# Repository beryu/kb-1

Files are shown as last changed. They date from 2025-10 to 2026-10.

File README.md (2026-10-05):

# komoro

komoroは、19mmトラックボールを搭載した左右分割キーボードです。

コンパクトな17mmピッチのカラムスタッカード配列を採用し、左右合わせて48キーを搭載しています。
トラックボールの高さを低く抑えることで、キーを打つときや持ち運びの邪魔になりにくくしています。
コントローラーにはSeeed Studio XIAO nRF52840 Plusを採用しています。XIAOは右側だけに搭載し、左右間はSamtec FTSHヘッダとFFSD-06-D-10.00-01-Nケーブルで接続します。PCとはBluetoothで通信しますが、動作中は右側USB-Cから常に給電する必要があります。

| 左側PCB | 右側PCB |
| --- | --- |
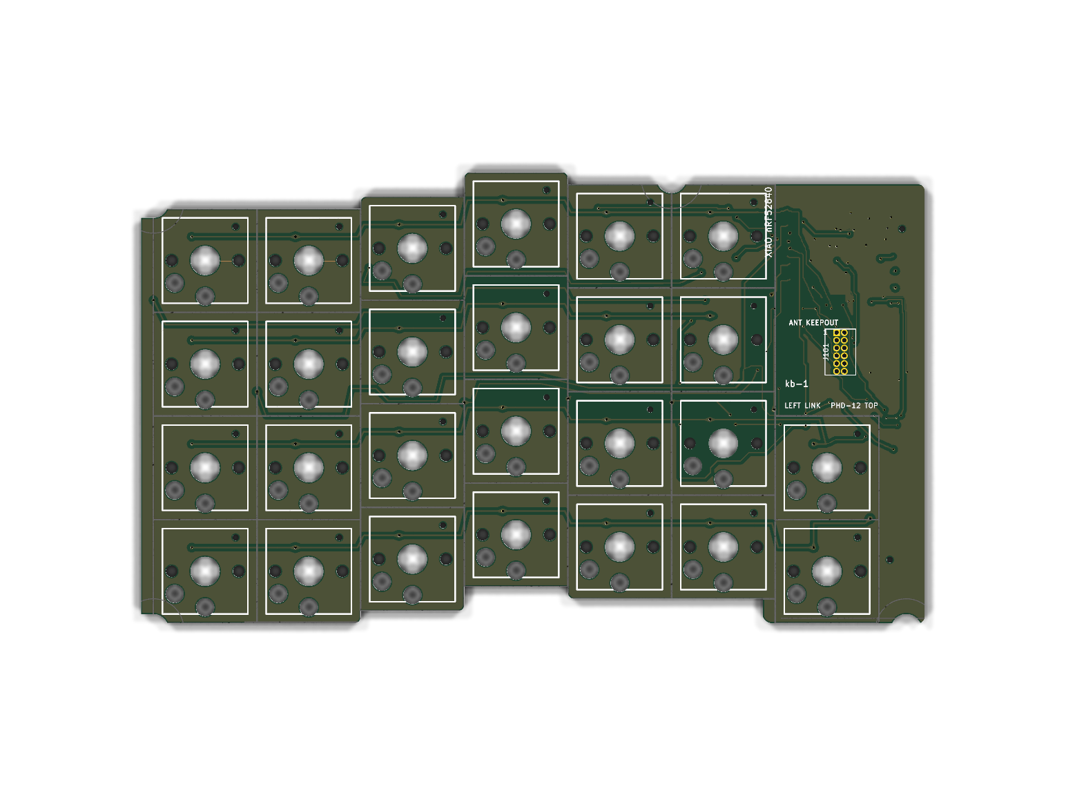
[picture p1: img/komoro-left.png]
komoro 左側PCB
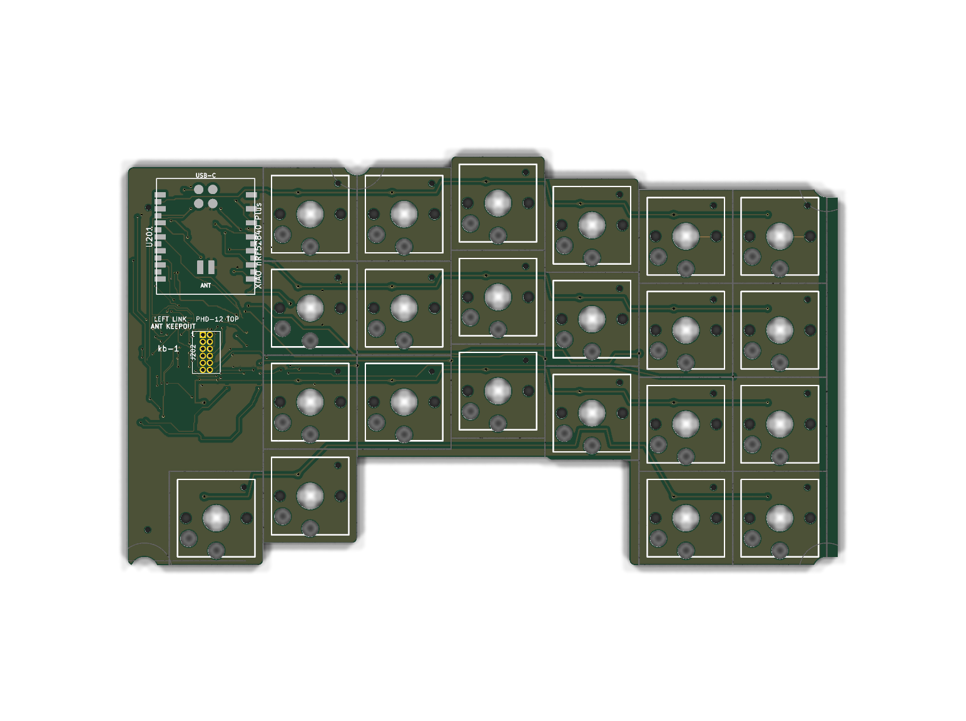
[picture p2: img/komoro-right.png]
komoro 右側PCB
|  |  |

※画像は旧リビジョンの基板です。現行のコネクタや部品配置は[`pcb/`の製造用PCBデータ](pcb/)を確認してください。

## [ビルドガイド](build-guide.md)

## 特徴

* 17mmピッチのカラムスタッカード配列
  * 左26キー、右22キーの48キー構成です。
* USB-C給電・Bluetooth接続
  * PCとの通信にはBluetoothを使用します。
  * 使用中は右側XIAOへモバイルバッテリーまたはUSB電源から常に給電する必要があります。
  * 電源スイッチはなく、USB-Cケーブルの接続／取り外しで電源を操作します。
  * 左右間は、Samtec FFSD-06-D-10.00-01-Nケーブルで接続します。
* Seeed Studio XIAO nRF52840 Plusを採用
  * XIAOは右側だけに搭載し、左側はコントローラーを持たない受動基板です。
* トラックボールの設置位置が調整可能
  * トラックボールを取り付ける位置を調整して、自分にとって一番操作しやすい位置に設置できます。ボールの高さを抑えたことでキーを打つときの邪魔になりにくくなっています。
* ZMK対応
  * [komoro専用ファームウェア](https://github.com/beryu/zmk-keyboard-kb-1)を公開しています。
  * keymap-editorやZMK Studioを使用して簡単にキーマップが変更できます。

## 使用上の注意

* 異臭や煙が出たときは、ただちにUSB-C電源を外して使用を中止してください。
* 左右を接続するFFSDケーブルは、USB-C電源を外した状態で抜き差ししてください。
* USB-C電源とケーブルは、破損や発熱のない適合品を使用してください。

## 設計データについて

本リポジトリでは、komoroの基板設計データと19mmトラックボールケースの設計データを公開しています。

19mmトラックボールケースには、PAW3222センサーモジュールのズレを抑える[ガイド追加版STL](3d-models/STL/trackball-case-19mm-ortho-sensor-fit-Body.stl)を用意しています。寸法と印刷・再生成方法は[センサー溝の調整説明](3d-models/FreeCAD/TRACKBALL-SENSOR-FIT.md)を確認してください。再生成の入力に使う従来版STLは残し、旧トラックボールケースのFreeCADファイルは削除しています。本体ケースのFreeCADデータとSTLは現行PCB外形、左右上面のFFSDコネクタ、右側USB-Cに合わせて更新しています。印刷前に実部品との干渉を確認してください。

ライセンスにしたがって自由に利用していただいて構いませんが、問い合わせには対応しません。

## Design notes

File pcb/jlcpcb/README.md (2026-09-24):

# JLCPCB発注データ

Samtec FTSH-106-01-L-D-Kを左右とも上面に縦挿しする基板から生成します。左J101と右J202はともに0°で、標準の両端FFSDケーブルに合わせて同番号端子へ同じ信号を割り当てています。左右ともKiCad DRCで未接続0件、短絡・クリアランス違反0件です。製造発注前に警告内容、ケーブルの実物結線、筐体内の高さ・取り回しを確認してください。

## 左右間ケーブル

既製の Samtec `FFSD-06-D-10.00-01-N`（2×6極、254 mm、標準両端ソケット）を使用します。`-RW`または`-R`型は使用しません。左J101→右J202は同番号対応です。

| 左J101 | 右J202 | 信号 |
| ---: | ---: | --- |
| 1 | 1 | LROW2 |
| 2 | 2 | COL4 |
| 3 | 3 | LROW0 |
| 4 | 4 | LROW1 |
| 5 | 5 | COL5 |
| 6 | 6 | COL6 |
| 7 | 7 | COL3 |
| 8 | 8 | COL2 |
| 9 | 9 | COL1 |
| 10 | 10 | GND |
| 11 | 11 | LROW3 |
| 12 | 12 | COL0 |

組み立て前に実物のケーブルで上記12組の導通と隣接ピン間の短絡がないことを確認してください。特にGND（10→10）の誤接続は通電前に確認します。

`bash pcb/jlcpcb/generate.sh` をリポジトリのルートで実行すると、`output/` に左右それぞれのGerber ZIP、BOM、CPL、DRCレポートに加え、左右を1回のPCBA注文にまとめるカスタマーパネルと`combined-drc.txt`を生成します。左右とパネルの電気的DRCエラーまたは未接続が1件でもある場合は生成を中断します。

結合パネルの生成にはKiKit 1.8.0が必要です。KiCad付属Pythonへ次のようにインストールしてください。

```sh
/Applications/KiCad/KiCad.app/Contents/Frameworks/Python.framework/Versions/Current/bin/python3 \
  -m pip install --user -r pcb/jlcpcb/requirements-panel.txt
```

JLCPCBでは次の結合ファイルを使用します。

- PCB: `output/combined-gerbers.zip`
- BOM: `output/combined-bom.csv`
- CPL: `output/combined-cpl.csv`

見積画面では`Different Design: 2`、`Delivery Format: Panel by Customer`、`PCB Color: White`、`Silkscreen: Black`、`PCBA Type: Standard`を選択します。実装対象のダイオード48個はすべて裏面配置なので、`Assembly Side: Bottom Side`を選択してください。BOM確認画面のファイル形式は`Complete File`を選択してください。ハンドリングレールとフィデューシャルは`Added by JLCPCB`のままとします。

このパネルは左右のPCBを2 mm間隔で縦に配置し、3か所のマウスバイトタブで連結する生成物です。レール追加前の外形範囲は約128.6 x 150.2 mmです。左右別々のファイルは、個別発注や診断用として引き続き生成します。

左右間の3か所のタブには直径0.5 mmのマウスバイト穴を両端に8個ずつ設け、穴の間の残り幅を約0.36 mmにしています。切断線を基板側に0.2 mm寄せているため、折った後の突起を抑えられます。ただしマウスバイトの細かな凹凸は残るため、外形を完全に平滑にするには分離後の軽い仕上げが必要です。JLCPCBの標準Vカットはパネル全幅を通る直線に限られ、この2 mmの隙間をまたぐ局所的な3本のタブだけには適用できません。

## ネジ用の逃げ

左右の基板に各4か所、合計8か所の円弧状の逃げを`Edge.Cuts`で設けています。元の`MountingHole_5mm`フットプリントは中心が基板外にあり、基板外形を切り欠かないままパネル化で一部が落ちていました。修正後は実際の基板外形がネジ位置を避けます。生成時に8か所の外形とネジ中心の距離を検査します。

修正前にアップロードしたGerberのJLCPCBプレビューにはこの逃げが反映されません。発注には再生成した`output/combined-gerbers.zip`をアップロードし、プレビューで8か所の円弧状の切り欠きを確認してください。

## ビア寸法

左右基板と結合パネルの全ビアは、穴径0.3 mm以上・外径0.5 mm以上です。JLCPCB見積画面の`Min via hole size/diameter`は標準の`0.3mm/(0.4/0.45mm)`を選択できます。生成時に全ビアの寸法を検査します。旧Gerberには0.2 mmと0.25 mmの穴があるため、必ず新しい`combined-gerbers.zip`をアップロードしてください。

## PCBA対象

- JLCPCB実装: 1N4148Wダイオード
- 手はんだ: 右側XIAO nRF52840 Plus、左右のSamtec FTSH-106-01-L-D-K（上面からFFSDケーブルを挿入）、Chocソケット、FFC変換基板

BOM/CPLは基板フットプリントの`exclude_from_bom`、`exclude_from_pos_files`および`LCSC`フィールドから生成します。JLCPCBへのアップロード後は、ダイオードの向きと当日在庫をプレビュー画面で必ず確認してください。

結合GerberはJLCPCBの基板外形認識と整合するKiCad CLIで生成します。左右の正本PCBには、パネル化の前に通常のCLI DRCを実行します。

## 回路図の再生成

左右の回路図はPCBを正として生成しています。PCBのパッド／ネットを変更した後は、KiCad付属Pythonで`pcb/generate_schematic_from_pcb.py <board> <output schematic> <left|right>`を実行し、親回路図に対してERCとネットリスト照合を行ってください。

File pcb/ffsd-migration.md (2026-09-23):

# FFSD左右間接続の設計記録

既製ケーブルは Samtec `FFSD-06-D-10.00-01-N`（2×6極、254 mm、標準の両端付き）を採用する。基板側は手はんだ可能なスルーホール `FTSH-106-01-L-D-K` を左右に1個ずつ使用する。両方を上面の縦挿しとし、ストレートケーブルに合わせて左右の**同番号端子に同じ信号**を割り当てる。

| 端子 | 左の信号 | 右の信号 |
| ---: | --- | --- |
| 1 | LROW2 | LROW2 |
| 2 | COL4 | COL4 |
| 3 | LROW0 | LROW0 |
| 4 | LROW1 | LROW1 |
| 5 | COL5 | COL5 |
| 6 | COL6 | COL6 |
| 7 | COL3 | COL3 |
| 8 | COL2 | COL2 |
| 9 | COL1 | COL1 |
| 10 | GND | GND |
| 11 | LROW3 | LROW3 |
| 12 | COL0 | COL0 |

基板側は `Library.pretty/Samtec_FTSH-106-01-L-D-K.kicad_mod` を使用する。Samtec の [FTSH製品図面](https://suddendocs.samtec.com/prints/ftsh-1xx-xx-xxx-d-xx-mkt.pdf) に従い、端子ピッチ1.27 mm、-K樹脂外形5.08 × 7.54 mm とした。穴径0.71 mmは Samtec の [推奨PCBレイアウト](https://suddendocs.samtec.com/prints/fts-dth.pdf) に基づく。ランド外径1.11 mmで片側の環状銅幅0.20 mmを確保し、マスク開口はランドと同寸にして隣接開口間0.16 mmとした。[JLCPCBのPTH環状銅幅・マスクブリッジ仕様](https://jlcpcb.com/capabilities/Capab)に合わせた。表面実装ではなくスルーホールで手はんだを想定する。

左J101は (123.2, 70.0) mm、右J202は (52.0, 151.0) mm を中心に、ともにF.Cu側、回転0°で実装する。ヘッダを上から差し込み、右側ではXIAO下部に置く。ケーブルは Samtec の標準 `FFSD-06-D-10.00-01-N` とし、`-RW`（Reverse Wiring）や `-R`（Reversed）型は使わない。左右の同番号ピンへ同じ信号を割り当てている。通電前に製品サンプルで12極の同番号導通、隣接間短絡、筐体内のキーとケーブル取り回しを確認する。

[FTSH-106-01-L-D-K の製品仕様](https://www.digikey.com/en/products/detail/samtec-inc/FTSH-106-01-L-D-K/7433351)では、はんだ側ポスト長は2.29 mm。基板厚1.6 mmを差し引いた裏面側の公称突き出しは約0.69 mmで、約3 mmの裏面空間に対し余裕がある。実際にははんだフィレットの高さもあるため、組立試作で確認する。

2026-09-23 のKiCad DRCでは、左右単体および結合パネルとも未接続0、短絡・クリアランス違反0。既存設計由来のシルク被りや不要な短い銅箔等の警告は残る。`replace_phd_with_ffsd.py` は設計過程の試行用スクリプトであり、製造時は正本PCBと `jlcpcb/output/` を使用する。

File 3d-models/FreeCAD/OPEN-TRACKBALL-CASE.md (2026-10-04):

# 19.05 mm 開放型トラックボールケース（試作）

写真のようにボール周囲の樹脂を減らすための別ケースです。既存のセンサーガイド追加版を基準に、ベアリング支持部の間の壁を3か所取り除いています。元ファイルは変更していません。完全に異なる取り付け方式へ変更するものではなく、センサー収納部・後方支持部・固定穴を引き継いだ開放型です。

- 印刷用：[`trackball-case-19mm-open-Body.stl`](../STL/trackball-case-19mm-open-Body.stl)
- FreeCAD表示用：[`trackball-case-19mm-open.FCStd`](trackball-case-19mm-open.FCStd)
- 生成スクリプト：[`generate-open-trackball-case.py`](generate-open-trackball-case.py)
- 検証結果：[`trackball-case-19mm-open-Body.validation.json`](../STL/trackball-case-19mm-open-Body.validation.json)

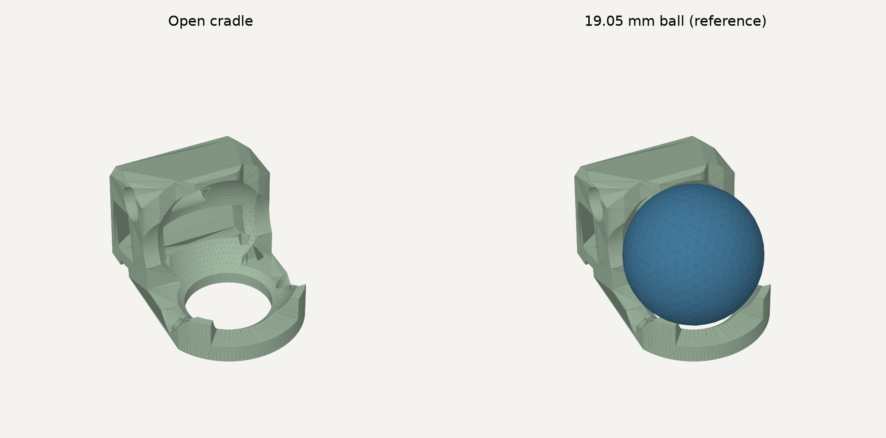
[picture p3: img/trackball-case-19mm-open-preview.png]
ケース単体とボール配置


## 構造

19.05 mm POMボール、4×1.5×2 mmベアリング3個、M1.4×5 mmのベアリング固定ねじ、既存センサーモジュールを使う想定です。後方のM2固定穴とセンサー溝を維持しています。下部2.5 mmのフレームを残し、前方と左右に開口を設けています。中央の底穴も元形状のままです。

ベアリング支持部の残る角度は前方の左右38〜78度と−78〜−38度です。後方のセンサー収納部はX≤−6 mmの領域を残しています。球面を樹脂で支える設計ではなく、組み立て時にはベアリング3個で支えてください。

保持用の壁が減るため、持ち運び時にボールが外れる可能性があります。スナップ保持は保証していません。強度・印刷公差・ベアリング外輪の回転余裕・実センサー部品との干渉は実物で未検証です。

## データ上の検証

元ケース内面の球面から求めた中心(0, 0, 9.8) mmを基準にしています。支持された実ボールの中心はまだ実測していません。この公称位置で半径10.025 mmの球（ボール半径9.525 mm＋0.50 mm）との重なり体積が0であることを、保存したSTLの再読み込み後に検証しました。

元の旧版とセンサーガイド追加版も、この同じ公称位置・半径では重なり体積0でした。したがって、現物の引っかかりをガイド追加だけのせいと断定する根拠はありません。開口は擦れ得る壁を減らし、接触の確認と清掃をしやすくする変更です。

閉じたメッシュ、面の向き、接続成分1、後方収納部と下部フレームの維持を検証しています。ベアリングやねじの実部品モデルを含む組立干渉検証ではありません。プレビューの球も位置参照用です。

## 印刷・確認

底面を下に配置してください。薄い壁とセンサー溝があるため、スライサーで壁の欠落やオーバーハングを確認し、必要なサポートを付けます。ベアリング座と溝に残ったサポートやバリは取り除いてください。

まずセンサーなしでベアリングとボールを組み、各方向に転がして擦れと支持部のたわみを確認してください。次にセンサーを装着して位置を調整します。取り付けねじの締め付け前後でも動きを確認してください。実機確認までは旧ケースの置き換え推奨にはしていません。

## 再生成

`numpy`、`trimesh`、`manifold3d`を使用します。プレビューには`matplotlib`が必要です。

```sh
python 3d-models/FreeCAD/generate-open-trackball-case.py \
  --preview img/trackball-case-19mm-open-preview.png \
  --freecadcmd /Applications/FreeCAD.app/Contents/Resources/bin/freecadcmd \
  --cad-output 3d-models/FreeCAD/trackball-case-19mm-open.FCStd
```

FreeCADを使わずSTLだけ生成する場合は、`--freecadcmd`と`--cad-output`を省略できます。FCStdは生成済みメッシュと非表示の参照球を収録しています。メッシュを寸法駆動するCADではなく、形状の変更はスクリプトの`BASE_HEIGHT`と`WINDOWS`で行ってください。

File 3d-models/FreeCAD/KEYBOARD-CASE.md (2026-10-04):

# Keyboard case generator

`generate-keyboard-case.py` reads both KiCad PCB files and regenerates the
bottom trays and top plates in FreeCAD. The PCB outline and the locations and
rotations of the key switches and XIAO footprints therefore stay synchronized
with the PCB design.

## Generate

From a terminal on macOS with FreeCAD installed in `/Applications`:

```sh
/Applications/FreeCAD.app/Contents/Resources/bin/freecadcmd \
  -c "exec(open('3d-models/FreeCAD/generate-keyboard-case.py').read())"
```

It can also be pasted directly into FreeCAD's Python console. Use the complete
absolute path on one line:

```python
exec(open('/absolute/path/to/torabo-tsuki-om/3d-models/FreeCAD/generate-keyboard-case.py').read())
```

The script detects checkouts stored under the conventional
`~/ghq/github.com/<account>/torabo-tsuki-om` path even though the FreeCAD Python
console does not define `__file__`. For a checkout elsewhere, start FreeCAD
from the repository directory or set `TORABO_TSUKI_OM_ROOT` before launching
FreeCAD.

Outputs are written to `3d-models/FreeCAD/generated/`:

- one editable FreeCAD document containing both halves;
- STL files for printing;
- STEP files for exchange and downstream CAD edits.

Open `torabo-tsuki-om-keyboard-case.FCStd` in FreeCAD. The model tree separates
the left/right halves, bottom trays, top plates, and hidden PCB references.

## Assembly hardware

The complete left/right enclosure uses the following printed parts and
hardware:

| Item | Quantity | Notes |
| --- | ---: | --- |
| [Left bottom tray](generated/left-bottom-tray.stl) | 1 | 3D printed |
| [Left top plate](generated/left-top-plate.stl) | 1 | 3D printed |
| [Right bottom tray](generated/right-bottom-tray.stl) | 1 | 3D printed |
| [Right top plate](generated/right-top-plate.stl) | 1 | 3D printed |
| M2 heat-set insert | 8 | Four per half. [Japan Drive-It Sonic Lock M2-3.0, MonotaRO order code 42131126](https://www.monotaro.com/p/4213/1126/) fits the 3.2 mm diameter, 4.0 mm deep pilot. It is sold in packs of six, so order two packs. |
| M2 x 3.5 mm low-profile screw | 8 | Original design specification for fastening the two top plates. |
| M2 x 4 mm ultra-low-head screw | 8 | Verified top-plate alternative: [AHN2 stainless screw, MonotaRO order code 69132245](https://www.monotaro.com/p/6913/2245/). Its M2 x 0.4 thread and 0.3 mm-high head fit; the extra 0.5 mm increases insert engagement to about 2.5 mm. One 13-piece pack is sufficient. |
| Thin self-adhesive rubber foot | 8 | Recommended for grip and bottom protection. |

Use either the 3.5 mm or 4 mm top-plate screws, not both. The printed bosses
replace the 4.5 mm spacers used by the original PCB top/bottom-plate stack, so
separate spacers, washers, and ordinary nuts are not required. The M2 x 4 mm
alternative above has only been checked for the enclosure top plates; continue
to use the specified M2 x 3.5 mm screw for the separate trackball-case mount.

## Design intent

The generator reads the current left and right `Edge.Cuts` and footprints. The
2026-09 PCB revision has a single right-side XIAO, no AAA holders or power
switches, and a vertical Samtec FTSH header on each side. The case has been
regenerated from those boards.

- The bottom is 1.5 mm thick, with 0.25 mm horizontal PCB clearance and a
  1.8 mm perimeter wall. The PCB is intended to sit with its top face level
  with the bottom-tray rim, supported by compressed foam around the inner
  perimeter. With this placement its underside is 3.0 mm above the tray floor;
  the FreeCAD PCB reference shows this installed position. A nominal 5 mm foam
  strip placed on the floor would compress to 3 mm, subject to the actual foam
  and screw preload.
- A 7 mm wide, 1 mm deep underside groove runs across each tray. A 9 mm wide,
  1 mm high rib directly above it leaves 1 mm of side material on each side
  and restores 1.5 mm of total material at the groove. The rib follows the
  calculated midpoint of adjacent Choc socket rows, including their stagger;
  both grooves align when the trays are mirrored bottom-to-bottom. The path
  avoids the magnet pockets. The plan-view corners have a 2.0 mm radius, and
  the groove mouth has a straight 0.4 mm chamfer, making its cross-section
  trapezoidal at the opening instead of leaving sharp cable-contact edges.
  Cable width, repeated
  folding at the far end,
  and the assembled cable route still need checking with the actual cable.
- Each bottom tray has four top-open pockets for 12 x 1 mm magnets. As in the
  supplied reference STL, the pockets are 12.1 mm in diameter and 1.0 mm deep,
  leaving 0.5 mm of material underneath. The upper pair follows the stepped
  case edge; each pocket has 7.0 mm clearance to its adjacent outer walls.
  The right positions are mirrored so all four pairs align when the two tray
  bottoms face each other for carrying.
- Each top plate is 1.5 mm thick, with its underside at the intended PCB top
  surface, and has
  20 switch windows measuring 14.2 x 14.0 mm, positioned from the KiCad
  footprints. The top plates and bottom trays are 3D-printed case parts.
- Each FTSH header has a 6.4 x 13.0 mm through-opening in its top plate for
  the FFSD-06 socket and upward cable exit. [Samtec's FFSD series drawing](https://suddendocs.samtec.com/catalog_english/ffsd.pdf) gives
  the unrelieved six-position socket body as 5.08 x 11.81 mm; the opening
  provides about 0.6 mm clearance per side. The left J101 and right J202
  footprints are both at 0 degrees, and each opening is centred on its
  connector body rather than the pin-1 footprint origin.
- Only the right plate has a raised XIAO cover and the right tray has a USB-C
  wall opening. The cover retains the white-label window, reset access hole,
  and LED viewing holes. The visible window is 10.5 x 12.5 mm, based on the
  supplied `xiao-nrf52840-plus-v2.step` label (10.2 x 12.2 mm). A wider
  11.2 x 13.2 mm underside pocket clears its metal shield (10.6 x 12.6 mm)
  while a 0.3 mm masking lip hides nearly all of the black border. Only the
  central USB-C region rises in a convex profile
  when viewed from the cable entry; the lower 9.8 mm pocket narrows toward the
  connector crown while the reset and LED areas retain the original roof.
  The metal shell extends 1.51 mm beyond the XIAO PCB and reaches 4.41 mm
  above the underside solder-pad plane. The pocket clears the complete STEP
  assembly with the bare XIAO held against the inverted top plate, and its
  roof remains 1.5 mm thick. The separate 12 mm wall opening provides the
  cable passage. The top plate also has a 12 mm wide, full-height notch starting
  at local X=11.5 mm, 0.8 mm before the STEP receptacle mouth, so the raised
  roof does not protrude in front of the port or block the plug housing.
- Four M2 insert bosses per half follow the former mounting-hole centres. The
  current boards have routed `Edge.Cuts` screw reliefs in place of the old
  `MountingHole_5mm` footprints. The bosses are 4.6 mm in diameter, with 3.2 mm
  insert pilots, 4.0 mm deep from the lowered tray top. The bosses extend to
  the tray bottom so their routed-edge portions have no underside gaps; each
  top plate has 2.4 mm screw holes.
- The right PCB's trackball cutout has a 34 mm back edge and continues one
  17 mm switch column to the right. The tray floor spans both areas, extends
  4.7 mm south of the former front edge, and has a 2 mm radius at both exposed
  southern corners. Its southern lip is 2.5 mm from the slot edge. The 44.2 x
  2.4 mm fastening slot and its shallow underside
  screw-head recess are shifted 5 mm south to align with the trackball case's
  forward fixing-hole row while leaving at least 2 mm at the north edge.
  The separate trackball-case STL is about 29.8 x 20.8 mm in plan view.
  At the lower-right corner of the third switch column from the right, a
  3.45 mm FFC slit passes through the wall at the PCB's stepped edge. The
  floor remains its full 1.5 mm thick beneath the slit.

The four generated STL files and the editable FreeCAD document are in
`generated/`. The STEP files are also exported for CAD exchange. The STL
meshes are checked for closure during generation. Check the printed cable
connector and trackball fit with physical parts before ordering a full set.

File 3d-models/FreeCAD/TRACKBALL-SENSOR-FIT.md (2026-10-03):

# 19 mmトラックボールケースのセンサーモジュール用ガイド

印刷には [`trackball-case-19mm-ortho-sensor-fit-Body.stl`](../STL/trackball-case-19mm-ortho-sensor-fit-Body.stl) を使用してください。再生成の入力に使う元STLは残しています。旧FreeCADファイルは削除し、調整版FCStdへ置き換えています。

対象は [sekigon-gonnoc/small-mouse-sensor-module](https://github.com/sekigon-gonnoc/small-mouse-sensor-module) のPAW3222モジュールです。READMEの「14×8 mm」は概略寸法で、[公式寸法図](https://github.com/sekigon-gonnoc/small-mouse-sensor-module/blob/main/img/size.png) の基板外形は **13.4×7.4 mm** です。

## 両側に貫通したセンサー溝

センサー溝は **-Y側と+Y側の両方に貫通** しています。位置決めストッパーは設けず、どちらからでも基板を挿入・取り外しでき、反対側から押し戻すこともできます。

| 項目 | 調整版 |
| --- | --- |
| 挿入・取り外し | 両側から可能 |
| ガイド間の短辺寸法 | 7.7 mm（基板7.4 mmに対して片側0.15 mm） |
| 長辺方向 | 貫通。位置決めストッパーなし |
| 基板背面の凹み | 約2.8 mmを確保し、両側に貫通 |
| 光学窓側の部品用凹み | 元の2.5 mmを維持 |

センサーを元ケースと同じ向きで保持し、側面の溝に基板端を合わせて中央まで滑り込ませます。短辺方向のガイドで横ズレと回転を抑えますが、長辺方向はスライドできます。光学窓、ボール支持部、固定穴、ケースの最大外形は維持しています。

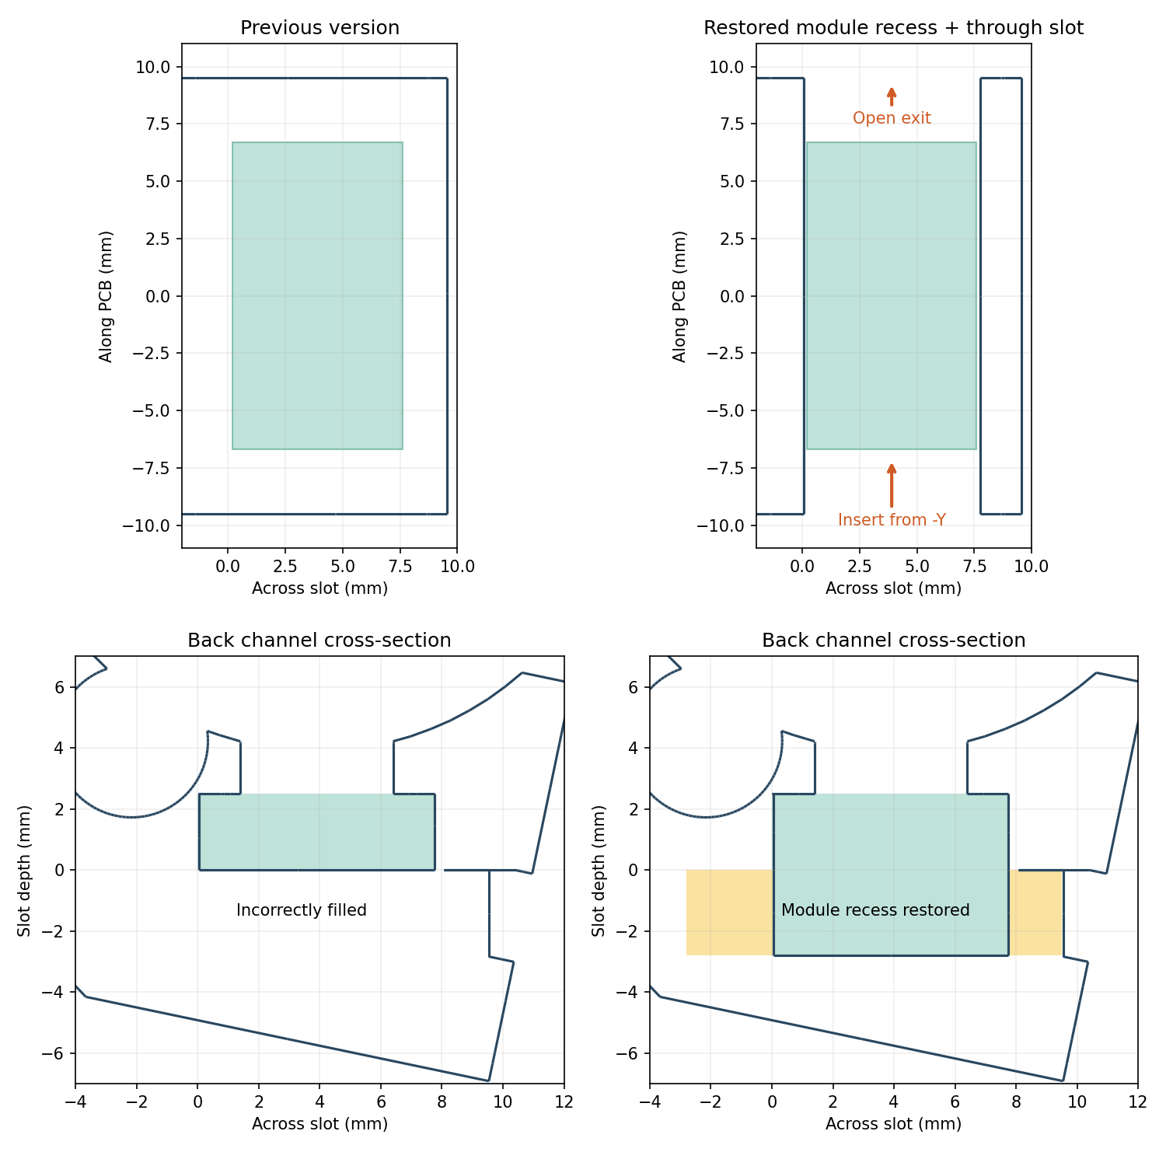
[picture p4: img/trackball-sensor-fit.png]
溝の断面と基板外形


片側0.15 mmは設計上の印刷余裕です。実機の印刷・組み付けは未検証です。まず試し刷りで挿入具合を確認してください。硬い場合は無理に押し込まず、生成スクリプトの `--clearance` で調整できます（0より大きく0.2 mm未満）。

## 背面空洞の補強

背面の空洞は単なる不要な隙間ではなく、センサーモジュールの基板を収める空間でもあります。[組み立て写真](../../img/trackball-case-3.JPG)と照合し、そのうち幅7.7 mmの基板通過領域を残しました。背面約2.8 mmと光学窓側2.5 mmの凹みをつなげた領域が、ケース側面の両端まで貫通しています。

補強材はこの通過領域の外側に限定しています。背面の隙間を全面的に埋めてしまうとモジュールの収納を妨げるため、必要な凹みは残しています。固定ねじ穴と光学窓も維持しています。

## FreeCADファイル

[`trackball-case-19mm-ortho-sensor-fit.FCStd`](trackball-case-19mm-ortho-sensor-fit.FCStd) は元STLと調整後STLのメッシュを収録しています。標準表示は `FittedCase` です。`OriginalCase` と表示を切り替えて比較できます。寸法プロパティは参照用で、形状変更は下記スクリプトで行ってください。

元のパラメトリックFreeCADモデルはFreeCAD 1.1で再計算すると既存のベアリング台座に複数ソリッドのエラーが出るため、調整版は印刷用STLを基準にしています。

## 再生成

Python環境に `numpy`、`trimesh`、`manifold3d` を用意し、リポジトリ直下で実行します。入力には元のSTLを使ってください。調整済みSTLを入力にすると隙間を広げられません。

```sh
python 3d-models/FreeCAD/fit-trackball-sensor.py \
  --input 3d-models/STL/trackball-case-19mm-ortho-Body.stl \
  --output 3d-models/STL/trackball-case-19mm-ortho-sensor-fit-Body.stl \
  --clearance 0.15
```

FreeCADファイルも保存する場合は `--freecadcmd` にFreeCADのコマンド実行ファイル、`--cad-output` に保存先FCStdを指定します。

STLは一般的なバイナリ形式です。微小面を0.0001 mmの許容差で整理し、保存時の頂点丸めによる非多様体化を防いでいます。生成時に元ケースの除去体積、追加ガイドの接続、面の向き、閉じたメッシュであること、保存後のSTLの再読み込みを検証します。今回の結果は追加体積252.255 mm³、除去体積は数値誤差範囲（0.000001 mm³未満）、接続成分1、閉じたメッシュです。調整版FCStdを再読み込みした際も閉じたメッシュであることを確認しました。

追加で、背面側の基板収納空間を含め、幅7.4 mm・深さ5.28 mm（約5.3 mmの元の空間から両面0.01 mmずつ控えた領域）をケースの片側から反対側まで掃引し、挿入・取り外しの干渉を検証しています。保存後STLでの干渉体積は0 mm³でした。基板だけでなく背面の凹みまで検証対象に含めています。

実モジュールの部品高さ、FPCの取り回し、印刷公差は実物で未検証です。背面固定ねじ穴と光学窓への非干渉、最大外形の維持も検証しています。

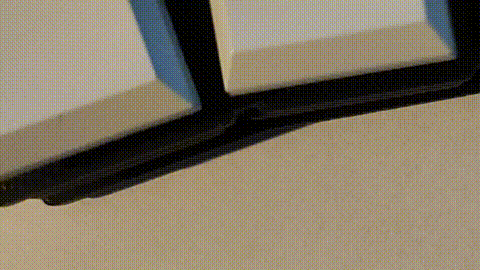
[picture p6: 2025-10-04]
img/led-1.gif

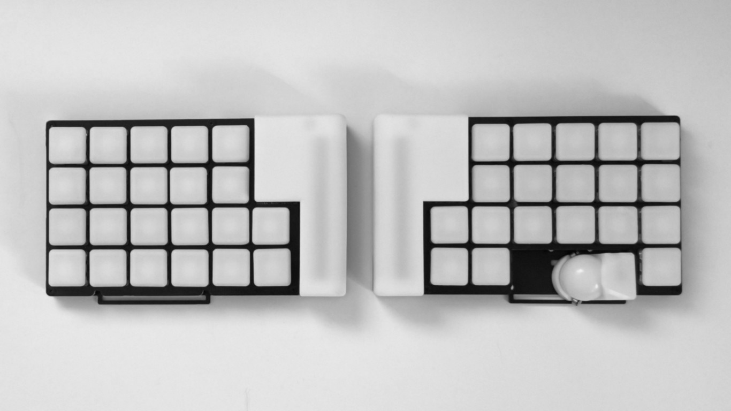
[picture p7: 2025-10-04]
img/torabo-tsuki-om-s.JPG

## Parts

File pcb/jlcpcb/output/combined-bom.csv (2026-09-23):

Comment | Designator | Footprint | LCSC Part # | MPN
1N4148W | D8,D9,D10,D11,D12,D13,D15,D16,D17,D18,D19,D20,D22,D23,D24,D25,D26,D27,D28,D29,D30,D31,D32,D33,D34,D35,D43,D44,D45,D46,D47,D48,D50,D51,D52,D53,D54,D55,D57,D58,D59,D60,D61,D62,D64,D65,D69,D70 | D_SOD-123_HandSoldering | C81598 | 1N4148W

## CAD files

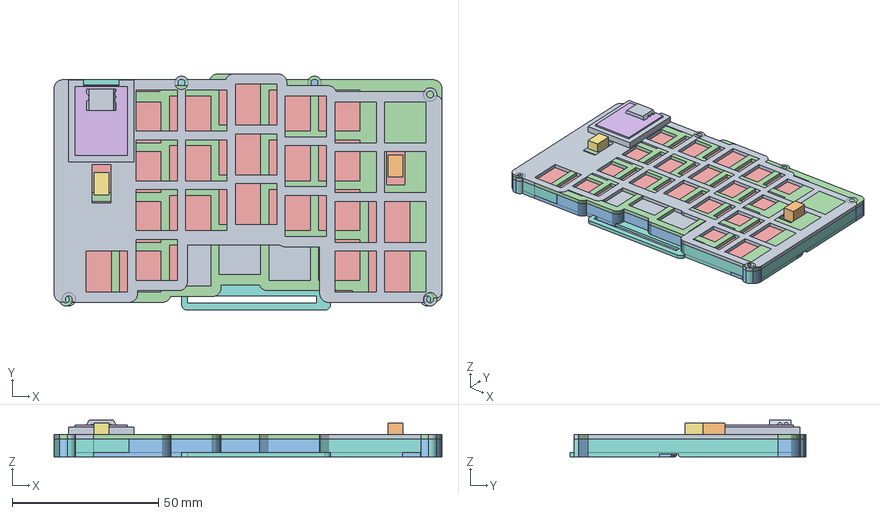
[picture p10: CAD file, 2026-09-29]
3d-models/FreeCAD/generated/torabo-tsuki-om-keyboard-case.FCStd
132.6 x 80.8 x 12.5 mm
PCB reference (1.6 mm) x 2
FTSH header body reference x 2
Left bottom tray x 2
Left top plate (26 switch windows) x 2
PCB reference (1.6 mm)001 x 2
XIAO nRF52840 Plus envelope reference x 2
FTSH header body reference001 x 2
Right bottom tray x 2
Right top plate (22 switch windows) x 2

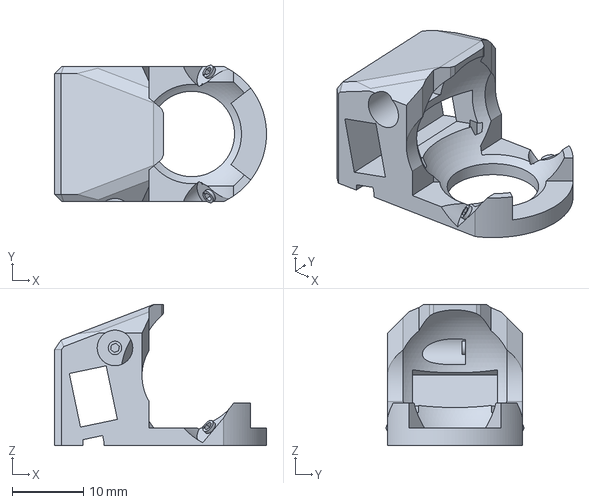
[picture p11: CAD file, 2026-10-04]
3d-models/FreeCAD/trackball-case-19mm-open.FCStd
29.8 x 19.4 x 19.8 mm

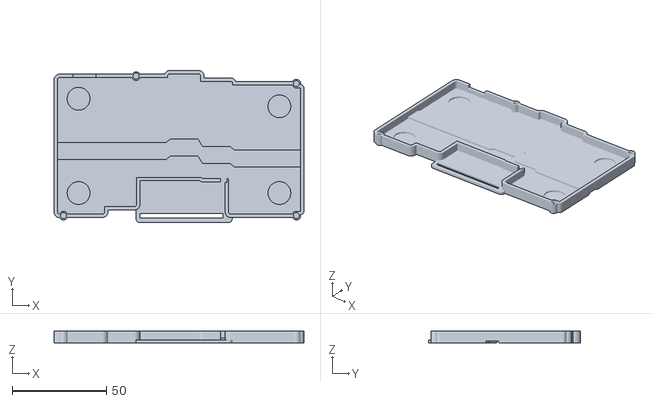
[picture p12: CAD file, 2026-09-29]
3d-models/FreeCAD/generated/right-bottom-tray.stl
132.6 x 80.8 x 6.10

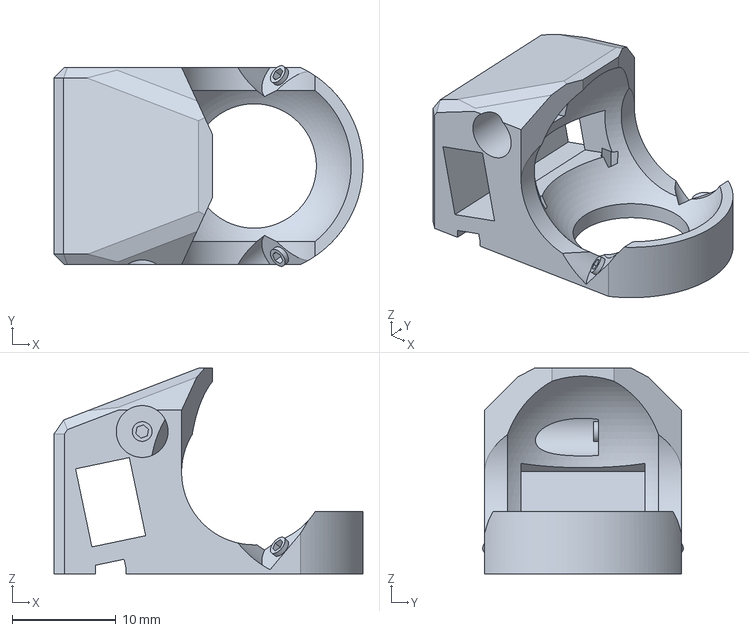
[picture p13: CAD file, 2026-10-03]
3d-models/FreeCAD/trackball-case-19mm-ortho-sensor-fit.FCStd
29.8 x 19.4 x 19.8 mm

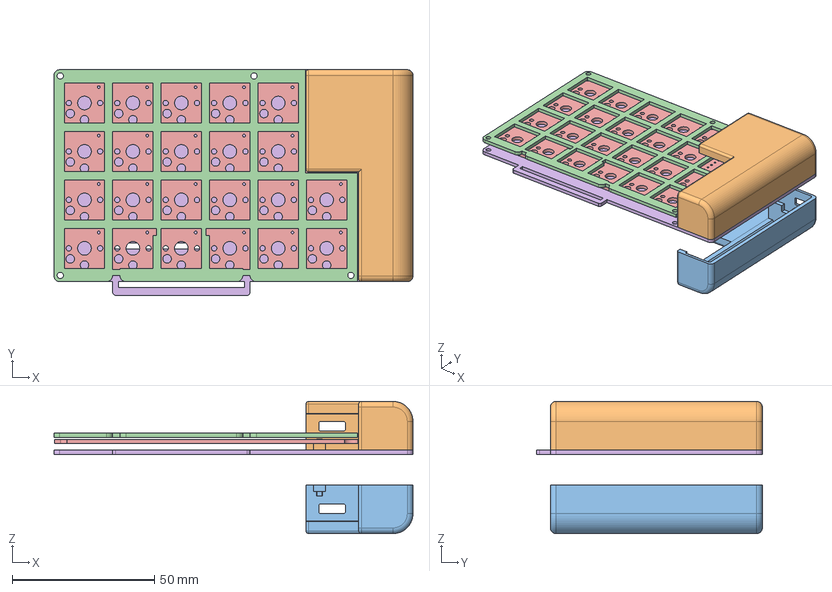
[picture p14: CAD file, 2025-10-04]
3d-models/FreeCAD/controller-cover-aa-ortho-mini.FCStd
126.0 x 79.2 x 46.4 mm
Body001 (Mirror #1)
torabo-tsuki-lp-S-ortho-mini-top_PCB
torabo-tsuki-lp-S-ortho-mini-left_PCB
torabo-tsuki-lp-S-ortho-mini-bottom_PCB

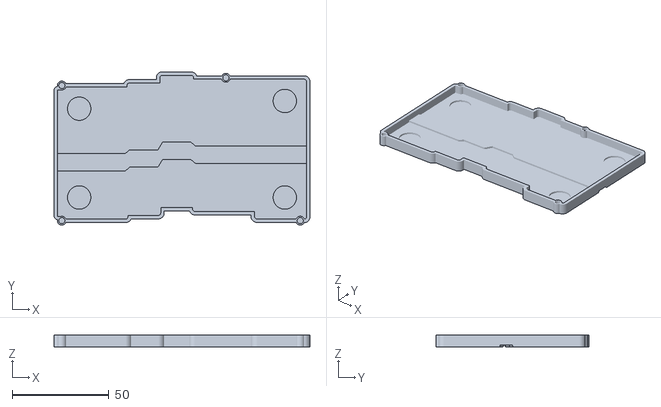
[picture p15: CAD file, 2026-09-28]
3d-models/FreeCAD/generated/left-bottom-tray.stl
132.6 x 79.3 x 6.10

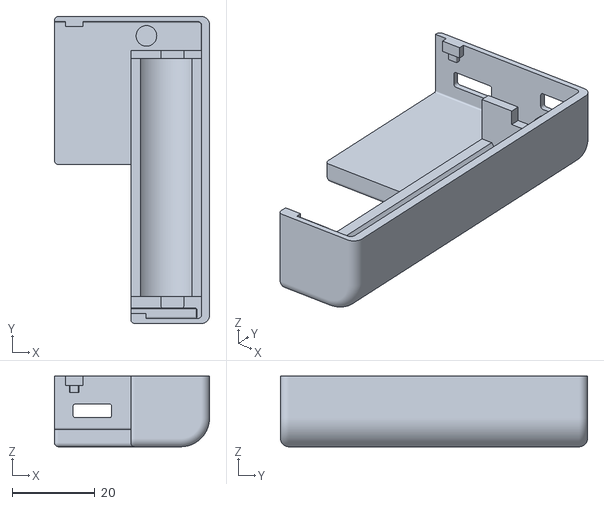
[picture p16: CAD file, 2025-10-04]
3d-models/STL/controller-cover-aa-ortho-mini-right.stl
37.6 x 74.4 x 17.1

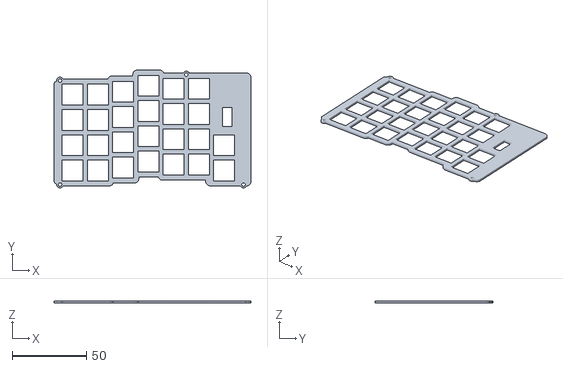
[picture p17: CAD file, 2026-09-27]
3d-models/FreeCAD/generated/left-top-plate.stl
132.6 x 79.3 x 1.50

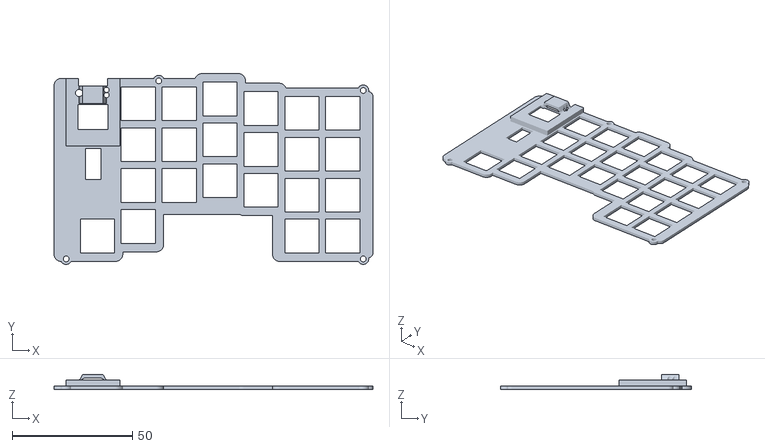
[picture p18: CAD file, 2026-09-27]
3d-models/FreeCAD/generated/right-top-plate.stl
132.6 x 79.3 x 6.41

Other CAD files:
3d-models/STL/trackball-case-19mm-open-Body.stl
3d-models/STL/trackball-case-19mm-ortho-sensor-fit-Body.stl
3d-models/STL/trackball-case-19mm-ortho-Body.stl
3d-models/STL/controller-cover-aa-ortho-mini-left.stl

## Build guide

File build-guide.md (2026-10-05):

## 部品

写真には旧リビジョンの基板が含まれます。左右間接続の部品・ピン配置・はんだ付け方向は、以下の現行記述と製造用PCBデータを優先してください。

| 名称 | 数 | 補足、入手先 |
| --- | ---- | --- |
| **本体関連** | | |
| メイン基板 | 各1  | JLCPCBなどで製造 |
| トッププレート | 2 | JLCPCBなどで製造 |
| ボトムプレート | 2 | JLCPCBなどで製造 |
| Seeed Studio XIAO nRF52840 Plus | 1 | [遊舎工房](https://shop.yushakobo.jp/products/10946)など。SenseではなくPlusを使用し、右側メイン基板へ表面実装します |
| Samtec FTSH-106-01-L-D-K（12極ヘッダ） | 2 | 左右各1。[DigiKey Japan](https://www.digikey.jp/ja/products/detail/samtec-inc/FTSH-106-01-L-D-K/7433351)など。1.27 mmピッチ、2列、スルーホール品。利用者が手はんだします |
| Samtec FFSD-06-D-10.00-01-N（両端ソケットケーブル） | 1 | [DigiKey Japan](https://www.digikey.jp/ja/products/detail/samtec-inc/FFSD-06-D-10-00-01-N/2651113)など。既製の12芯・254 mm品。`-RW`や`-R`型は使用しません |
| スペーサー(4.5mm) | 8 | [ヒロスギネット](https://www.hirosugi-net.co.jp/shop/g/g2387/), [遊舎工房](https://shop.yushakobo.jp/products/a0800r2?variant=47615915294951)など |
| SMDダイオード(1N4148W、SOD-123) | 48 | JLCPCB PCBA対象。LCSC品番 C81598 |
| スイッチソケット(Choc) | 48 | [遊舎工房](https://shop.yushakobo.jp/products/a01ps?variant=37665172553889)など。手はんだ |
| ねじ(M2x3.5) | 18 | [ウィルコ](https://wilco.jp/products/F/FX-EB.html#page3)など |
| **トラックボール部品** | | |
| トラックボールセンサー(14mmマウスセンサーモジュール)、FFCコネクタ変換基板付き | 1 | [BOOTH](https://booth.pm/ja/items/6520217) |
| フレキシブルケーブル(0.5mmピッチ、6P、150mm、電極同一面) | 1 | Amazon, Aliexpressなど |
| ベアリング(4x1.5x2 mm) | 3 | [Amazon](https://www.amazon.co.jp/dp/B0CV75YFQY)など |
| ねじ(M1.4x5 mm) | 3 | Amazonなど |
| **その他** | | |
| キースイッチ(Choc V2) | 48 | Lofree系も可 |
| キーキャップ | 適量 | 17mmピッチのもの |
| 19.05mm POMボール | 1 | Aliexpressなど |
| 本体ケース、トラックボールケース | 1式  | 左右上面のFFSDコネクタと右側USB-Cへアクセスできる形状が必要です。既存ケースを使う場合は干渉を確認してください |
| ゴム足 | 8 | GRIPLUSなど薄型の物がおすすめです |
| USB-C電源 | 1 | モバイルバッテリーまたはUSB電源。PCとの通信はBluetoothを使用できます |

### 3Dプリント外装ケースを使用する場合

[`3d-models/FreeCAD/generated`](3d-models/FreeCAD/generated/) のケースは現行PCB外形と左右上面のFFSDコネクタに合わせて再生成済みです。トッププレートには両側のケーブル開口があり、XIAO用カバーとUSB-C開口は右側のみです。印刷前に実部品でケーブルとトラックボールの干渉を確認してください。左右ボトムケースと左右トッププレートを使う場合は、従来のPCB製トッププレート、PCB製ボトムプレート、4.5 mmスペーサーを使用しません。

外装ケースの組み立てには次の部品を使用します。

| 名称 | 使用数 | 補足、具体的な入手先 |
| --- | ---: | --- |
| M2熱圧入インサート | 8 | 左右各4。[日本ドライブイット「ソニックロック M2-3.0」注文コード42131126](https://www.monotaro.com/p/4213/1126/)を使用可能。ケースの下穴φ3.2 mm、深さ4.0 mmに適合します。6個入りのため2パック必要です。 |
| M2×3.5 mm低頭ねじ | 8 | トッププレート固定用の設計指定寸法。 |
| M2×4 mm超低頭ねじ | 8 | トッププレート固定用の代替品として[大阪魂「2X4(AHN2)」注文コード69132245](https://www.monotaro.com/p/6913/2245/)を使用可能。M2×0.4、頭高さ0.3 mm。13本入り1パックで足ります。 |
| PCB支持用の圧縮可能なフォーム材 | 適量 | ボトムケース内周でPCBを支えます。厚さ5 mmを約3 mmに圧縮する設計目安です。実際の材質とはんだ付けした部品に合わせて調整してください。 |
| 円形磁石（直径12 mm、厚さ1 mm） | 8 | 任意。左右各4か所のポケット用。持ち運び時に左右の底面を合わせる場合に使用します。 |
| 薄型粘着式ゴム足 | 8 | 構造上は任意ですが、滑り止めと底面保護のため推奨します。 |

トッププレート固定ねじはM2×3.5 mmまたはM2×4 mmのどちらか一方を使用します。上記M2×4 mm品はトッププレート固定についてのみ確認済みです。トラックボールケースの固定には、設計指定のM2×3.5 mm低頭ねじを使用してください。

## 必要な工具
- はんだごて、はんだ
- フラックス
- テスター（導通・短絡確認用）
- ニッパー
- ペンチ
- ドライバー
- （やすり）
- PC
- USBケーブル

## 3Dプリント部品の製造(JLC3DP利用)

[JLC3DP](https://jlc3dp.com/jp/3d-printing-quote)にアクセスします。

使用する構成に合わせて、必要なSTLだけをアップロードします。

| 部品 | 印刷ファイル | 数 |
| --- | --- | ---: |
| 左ボトムケース | [left-bottom-tray.stl](3d-models/FreeCAD/generated/left-bottom-tray.stl) | 1 |
| 左トッププレート | [left-top-plate.stl](3d-models/FreeCAD/generated/left-top-plate.stl) | 1 |
| 右ボトムケース | [right-bottom-tray.stl](3d-models/FreeCAD/generated/right-bottom-tray.stl) | 1 |
| 右トッププレート | [right-top-plate.stl](3d-models/FreeCAD/generated/right-top-plate.stl) | 1 |
| トラックボールケース | [trackball-case-19mm-open-Body.stl](3d-models/STL/trackball-case-19mm-open-Body.stl) | 1 |

PCB製プレートを使う場合は、トラックボールケースのみ印刷します。トラックボールケースは上記の`trackball-case-19mm-open-Body.stl`を使用してください。`3d-models/STL/`に残る旧コントローラーカバーは、上記の現行3Dプリント外装には使用しません。本体ケースの詳細は[本体ケースの設計・組立説明](3d-models/FreeCAD/KEYBOARD-CASE.md)を確認してください。

以下の画面写真は発注操作の参考です。選択肢や料金は発注時の画面で確認してください。

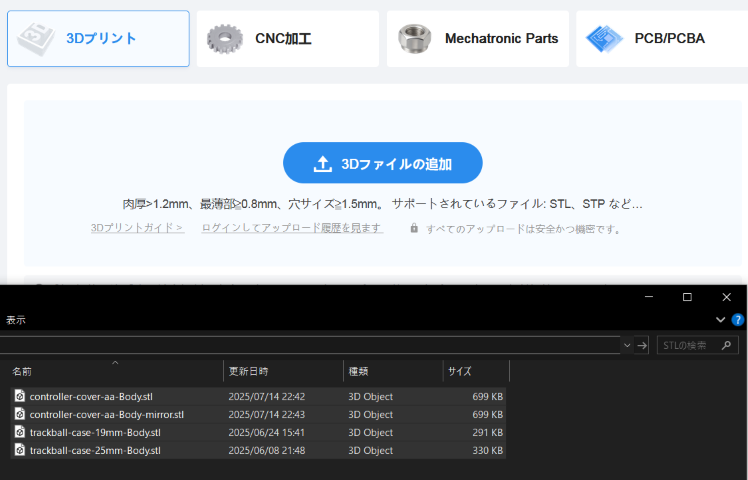
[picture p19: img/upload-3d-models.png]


読み込んだすべてのファイルについて、商品概要は`エンクロージャー...`から`プラスチックエンクロージャ`を選択します。

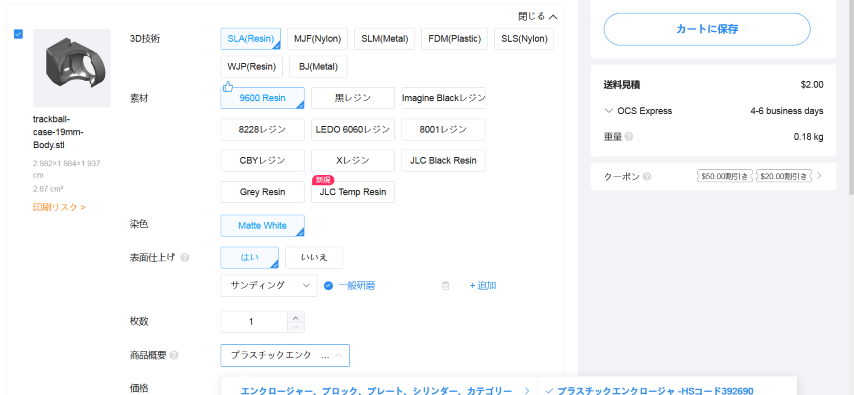
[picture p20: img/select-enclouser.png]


モデルのサムネイルの下に`印刷リスク`の表示がある場合は`はい`をチェックしてください。

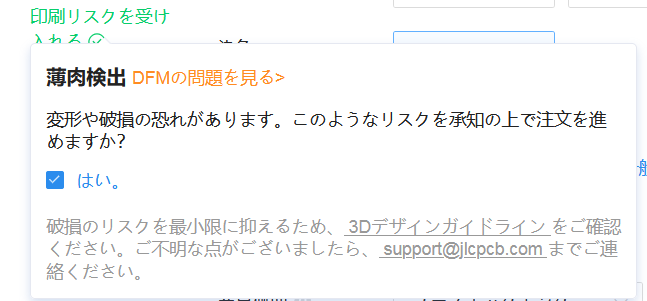
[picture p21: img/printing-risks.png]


カートに保存し、注文手続きを進めます。配送方法、送料、割引の適用条件は発注時の見積もりで確認してください。

発注履歴が表示されるようになった状態で数分経ってからタブをリロードすると、ファイル名の横に!マークが表示されることがあります。

その場合は!マークをクリックし、`はい`を選択してください。

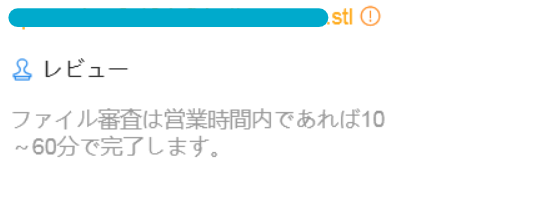
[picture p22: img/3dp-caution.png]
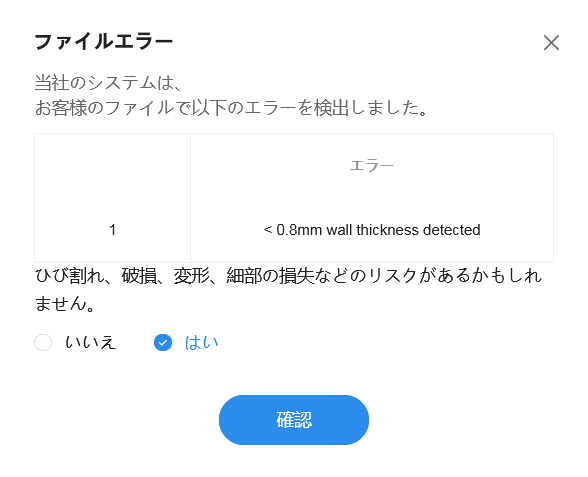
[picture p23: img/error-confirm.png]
|  |  |
| --- | --- |

JLC3DPのレビューで問い合わせが来た場合は、指摘された薄肉部や寸法への影響を確認してから製造可否を回答してください。必要に応じてCADデータを修正します。

## メイン基板をJLCPCBへ発注する

リポジトリのルートで次を実行し、`pcb/jlcpcb/output/`に発注データを生成します。

```sh
bash pcb/jlcpcb/generate.sh
```

通常は`combined-gerbers.zip`を1件のPCBとしてアップロードし、`Different Design: 2`、`Panel by Customer`、標準の`0.3mm/(0.4/0.45mm)`ビア、Standard PCBA、裏面実装を選択します。BOM/CPLには`combined-bom.csv`と`combined-cpl.csv`を指定し、ファイル形式は`Complete File`を選択してください。ハンドリングレールとフィデューシャルはJLCPCBに追加してもらいます。詳しい設定は[`pcb/jlcpcb/README.md`](pcb/jlcpcb/README.md)を参照してください。

左右を個別に発注する場合は、従来どおり`left-*`と`right-*`をそれぞれ使用できます。どちらの方法でも、アップロード後の部品配置プレビューでダイオードの向きを確認してください。

右側のXIAO nRF52840 Plus、左右のSamtec FTSHコネクタ、Chocソケット、FFC変換基板はBOM/CPLから除外されているため、別途用意して手はんだします。昇圧回路、電池関連部品、電源スイッチはありません。

## 組立手順

### トッププレートのトラックボール搭載部分を切り離す（PCB製プレートのみ）

3Dプリント製トッププレートではこの作業は不要です。PCB製トッププレートを使用し、ニッパーでそのまま切り離せない場合は、表裏に切れ目を入れてから折り取ってください。

### スイッチソケットをはんだ付けする

PCBAを利用した場合、ダイオードは実装済みです。ダイオードの向きがシルク表示と合っていることを確認してから、Chocソケットを手はんだします。PCBのみを発注した場合は、先に1N4148Wもはんだ付けしてください。

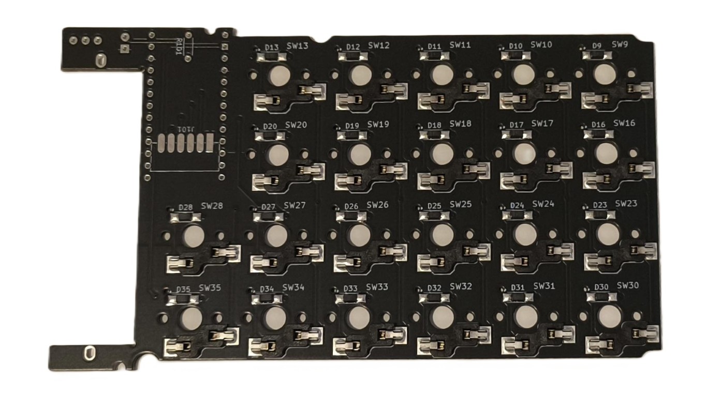
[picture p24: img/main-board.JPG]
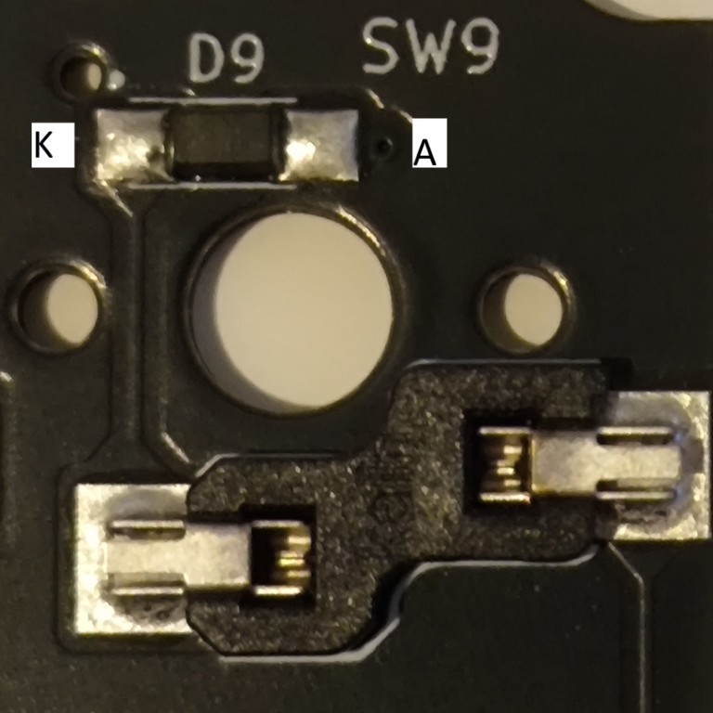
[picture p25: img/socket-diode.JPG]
|||
|-|-|

### 右側にXIAOをはんだ付けする

Seeed Studio XIAO nRF52840 Plusは右側だけに表面実装します。左側は受動マトリクスなのでXIAOを搭載しません。XIAOをシルクの`USB-C`と`ANT`表示に合わせて仮置きし、外周端子とPCB側ランドが重なっていることを確認します。

外周の対角にある2端子を少量のはんだで仮固定し、位置がずれていなければ残りの外周端子をフラックスとはんだごてではんだ付けします。14個の標準端子に加え、間に並ぶ9個の細い端子も確認してください。PCB側のランドは外側へ延ばしてあります。隣の端子とのブリッジに注意します。

XIAO裏面の6端子に対応する位置には、PCBを貫通する直径0.6 mmのめっき穴があります。外周を固定した後、PCBを裏返し、各穴にフラックスを付けます。穴の銅めっきとその奥のXIAO端子を加熱して、裏側から少量ずつはんだを流し込みます。これらはピンヘッダを差し込む穴ではありません。`SWDIO`・`SWDCLK`・2つの`GND`を確実に接合してください。`RESET`と`BAT`は現行回路では未接続ですが、同じ方法ではんだ付けできます。作業後は隣接端子間の短絡がないことを確認します。

電源スイッチはありません。USB-Cケーブルを接続すると起動し、外すと電源が切れます。

### トラックボールセンサーのアダプタ変換基板をはんだ付けする

XIAOの裏面端子をはんだ付けしてから、右側PCB裏面の6つのランド（`J201`）にアダプタ変換基板を重ねてはんだ付けします。アダプタ基板の端がXIAO裏面端子用のめっき穴を覆っていないことを確認してください。ランドは端子穴との間隔を確保するため長さ3 mmです。隣接するランド間のブリッジと、めっき穴へのはんだの流れ込みに注意します。

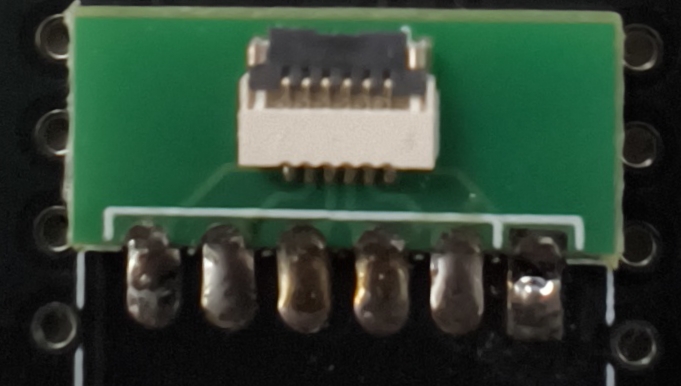
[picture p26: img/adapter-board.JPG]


### 左右のSamtec FTSHコネクタをはんだ付けする

左右それぞれの`J101`／`J202`へFTSH-106-01-L-D-Kを表側から差し込み、基板シルクの「1」と部品の1番ピンを合わせて裏側ではんだ付けします。ソケットは基板上方から挿入します。裏面のはんだと端子がケースに触れないこと、全12端子にブリッジがないことを確認してください。

指定の既製FFSDケーブルを使用します。PCB上では左右の同番号端子に同じ役割を割り当てています。ピン配列は次のとおりです。

| ピン | 信号 |
| ---: | --- |
| 1 | LROW2 |
| 2 | COL4 |
| 3 | LROW0 |
| 4 | LROW1 |
| 5 | COL5 |
| 6 | COL6 |
| 7 | COL3 |
| 8 | COL2 |
| 9 | COL1 |
| 10 | GND |
| 11 | LROW3 |
| 12 | COL0 |

導通試験では各ピンが反対側の同番号だけにつながり、隣接ピンと短絡していないことを確認します。コネクタおよびケーブルの抜き差しはUSB-C電源を外してから行ってください。

### トッププレート・メイン基板にスイッチを差し込む

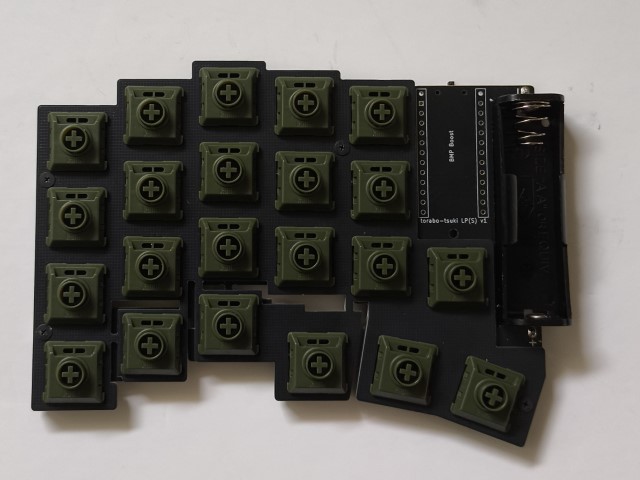
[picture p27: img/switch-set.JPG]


### ファームウェアを書きこむ

* このPCBはXIAO nRF52840 Plus用です。BLEMicroPro/BMP Boost用UF2には互換性がありません。
* 左右のFFSDケーブルを接続し、XIAOをPCにUSBケーブルで接続します。
* XIAOのRESET操作を素早く2回行ってUF2ブートローダーに入ります。必要に応じてXIAO上のRESET接点をGNDへ2回短絡します。
* このPCBには、右XIAO 1台で8行×7列を走査する専用ファームウェアが必要です。従来のCentral／Peripheral 2台構成のUF2は使用できません。
* [専用ファームウェアのGitHub Actions](https://github.com/beryu/zmk-keyboard-kb-1/actions)から現行基板用ビルドの成果物を取得し、`kb_1.uf2`をマウントされたストレージへコピーします。左側への書き込みは不要です。`settings_reset.uf2`はBluetooth設定のリセット用で、通常のファームウェアではありません。書き込み後はUSBケーブルを抜き、使用するUSB-C電源へ接続し直します。

### 3Dプリント外装ケースを準備する（3Dプリント外装のみ）

* 左右ボトムケースの各4か所にM2熱圧入インサートを取り付けます。下穴は直径3.2 mm、深さ4.0 mmです。
* 磁石を使う場合は、左右各4か所の直径12.1 mm、深さ1.0 mmのポケットへ取り付けます。左右の底面を合わせたときに対応する磁石が引き合う向きにしてください。
* ボトムケース内周にフォーム材を配置し、PCB上面がケースの縁と同じ高さになるように支えます。この位置ではPCB裏面とケース床の間隔は3.0 mmです。フォーム材はソケット、はんだ付け部、磁石ポケットを避けて配置し、ねじを締めたときの圧縮量を調整します。
* ケース底面のケーブル溝と上面のFFSD開口、右側USB-C開口で、実際のケーブルが無理なく通ることを確認します。

### トッププレートにスペーサーをねじ止めする（PCB製プレートのみ）

* PCB製トッププレートには4.5 mmスペーサーをねじ止めします。3Dプリント外装ではボトムケースのボスとインサートを使用するため、この作業は不要です。

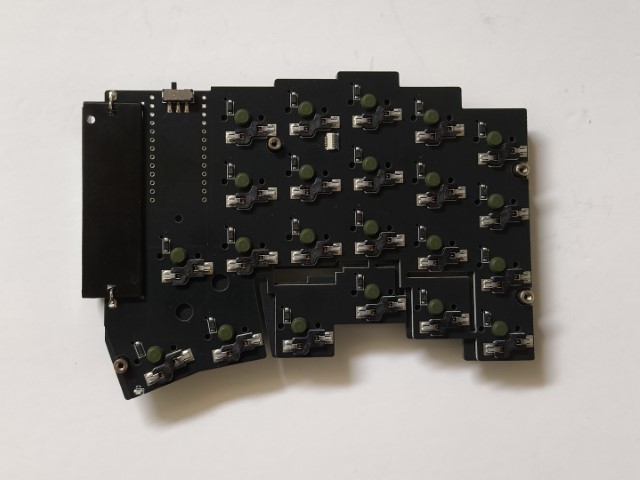
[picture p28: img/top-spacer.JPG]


### トラックボールケースにベアリングをネジで固定する

* ケースに空いている穴にねじを押し込みながら回すようにしてベアリングを固定します。
* ベアリングは多少ガタつきますが問題ありません。

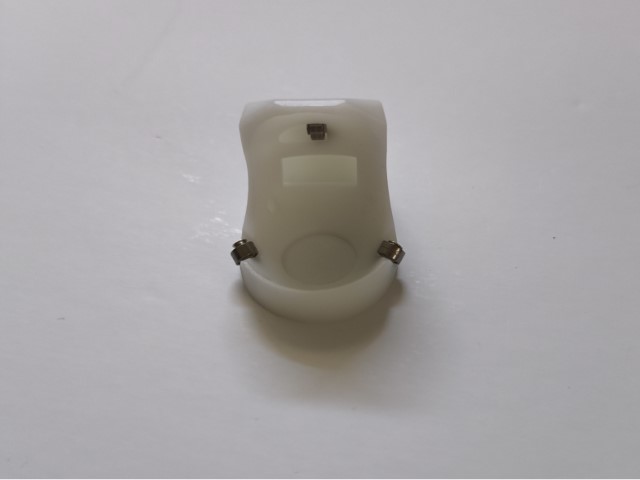
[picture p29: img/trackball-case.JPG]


### トラックボールセンサーにケーブルを差し込む

* コネクタのフラップ（黒い部分）を上に持ち上げ、トラックボールのケーブルをしっかり奥まで差し込み、フラップを下げます。
  * [コネクタの操作方法と注意点をよく確認してください](https://www.hirose.com/ja/product/document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)

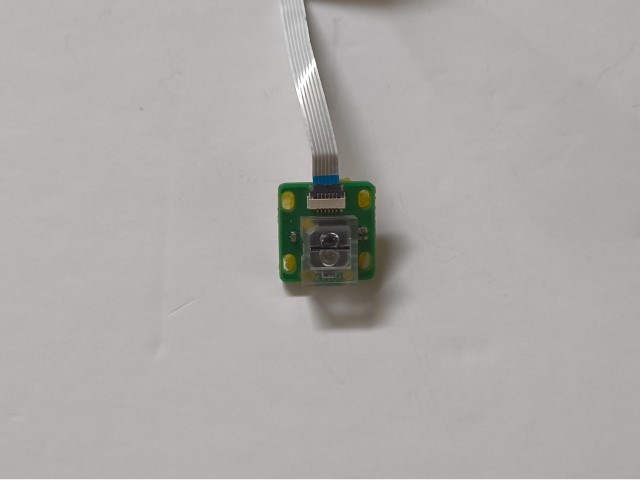
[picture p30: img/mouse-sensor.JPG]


### トラックボールのケーブルをメイン基板のコネクタに差し込む

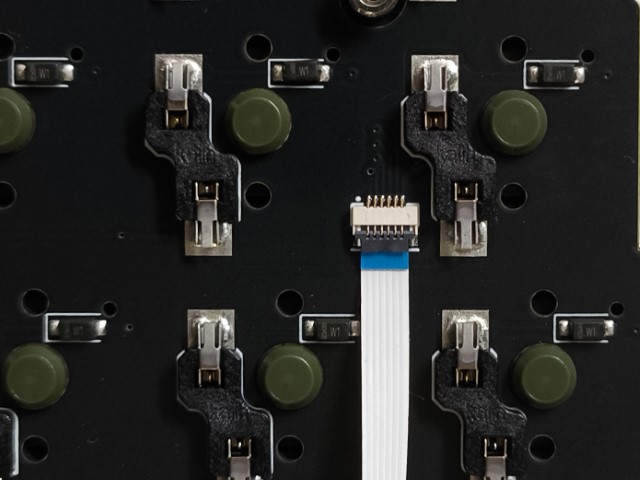
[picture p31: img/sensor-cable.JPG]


### センサーの動作確認をする

* XIAOへUSB-Cで給電し、PCとBluetoothでペアリングします。公開ファームウェアではUSB HID出力が無効のため、USBケーブルをつなぐだけではカーソルは動きません。
* センサーのレンズ側を机から2mmくらい浮かせてセンサー基板を動かしたり、レンズの上空を指で動かしたりしてマウスカーソルが動くならば、センサーは正常に動作しています。 
* センサーの動作確認ができたらUSBケーブルは取り外してください。

### トラックボールセンサーをケースに取り付ける

* 下の写真を参考にセンサー基板をケースに取り付け、レンズ位置をボールに合わせて調整してください。
* トラックボールの反応が悪い場合には取り付け位置を調整してください。

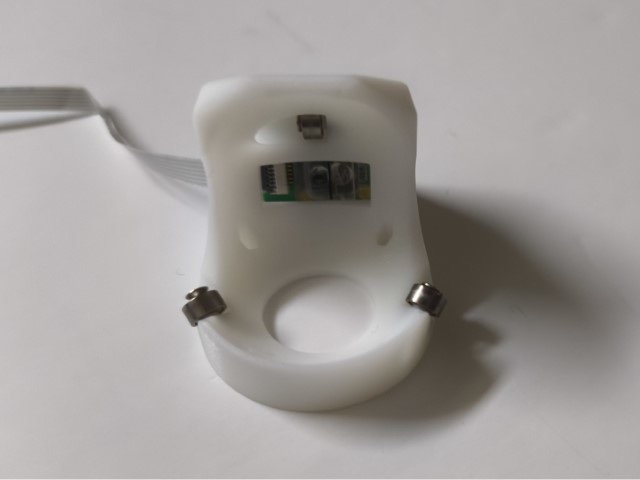
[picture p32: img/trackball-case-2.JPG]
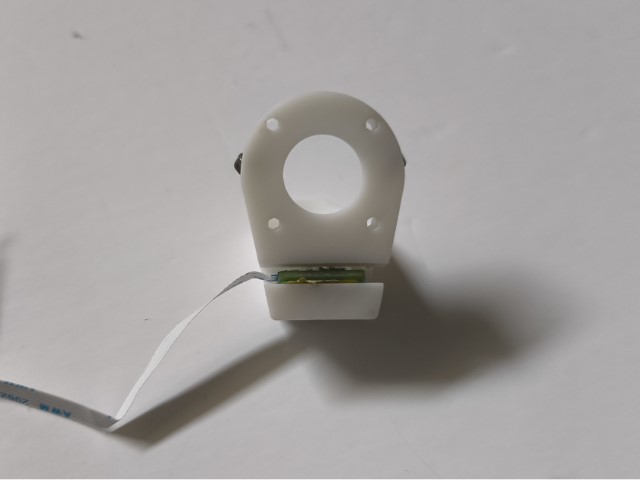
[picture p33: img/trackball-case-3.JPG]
|||
|-|-|

### ボトムプレートまたはボトムケースを取り付け、トラックボールケースを固定する

* PCB製プレートでは、スペーサーにボトムプレートを固定します。
* 3Dプリント外装では、フォーム材で支持したPCBにトッププレートを重ね、左右各4本のM2×3.5 mm低頭ねじまたは確認済みM2×4 mm超低頭ねじでボトムケースのインサートへ固定します。
* トラックボールケースは右側ボトムプレートまたはボトムケースへ、M2×3.5 mm低頭ねじで固定します。3Dプリント製ボトムケースでは長穴に沿って位置を調整し、FFCケーブルを壁のスリットへ通して、挟み込みがないことを確認します。

以下はPCB製プレートの組立写真です。

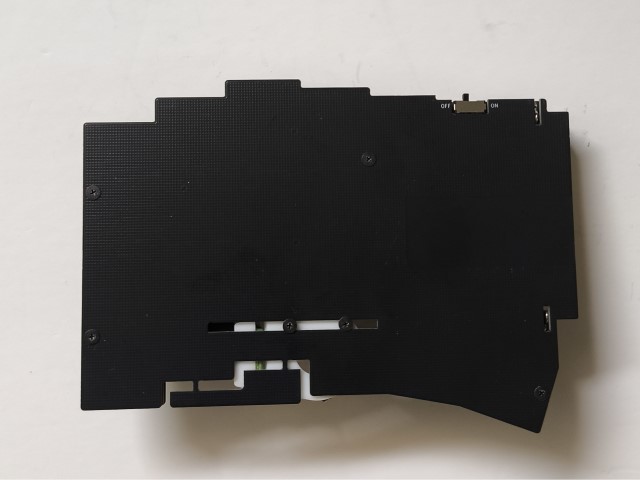
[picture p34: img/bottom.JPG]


### トラックボールケースにボールを入れる

* ボールをケースに押し込んで入れます。

### ゴム足を付ける

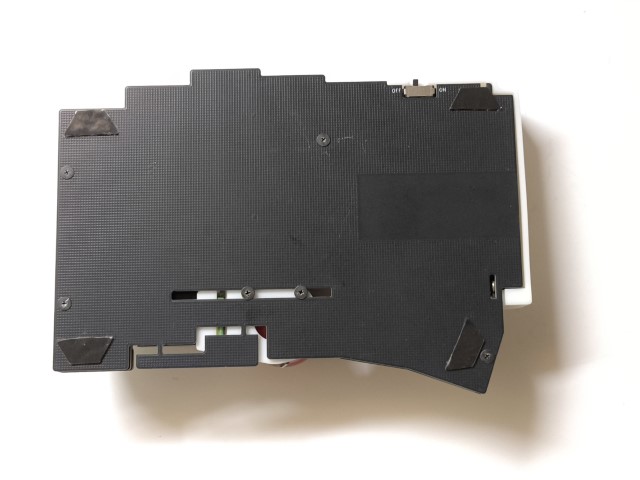
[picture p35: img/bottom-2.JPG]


### キーキャップを取り付ける

**以上で組立は完了です、お疲れさまでした。**

## 使い方

### 電源の説明

* 左右のFFSDケーブルを接続してから、右XIAOのUSB-Cへ給電します。USB-Cケーブルを接続すると電源ON、外すと電源OFFです。
* PCとBluetooth接続したい場合は、モバイルバッテリーまたはUSB電源アダプターから給電します。公開ファームウェアではUSB HID出力が無効です。PCのUSB端子から給電する場合も、キーとポインターの入力にはBluetooth接続を使用します。

### 無線接続

* USB-C給電し、接続先のデバイスでペアリングします。

### キーマップを変更する

* [ZMK Studio](https://zmk.studio/)では、PCとBluetooth接続した状態でキーマップを変更できます。
* [Keymap-Editor](https://nickcoutsos.github.io/keymap-editor/)でファームウェアのキーマップを編集することもできます。
* Keymap-Editorを使用する場合は[komoro専用ファームウェア](https://github.com/beryu/zmk-keyboard-kb-1)をクローンして編集してください。

## FAQ

まずはZMKのドキュメントを確認してください。

### 無線接続に問題がある

* 電源が入っているか確認してください。
* ZMKのドキュメントを確認してください。

### トラックボールの動きだしが遅い

* 一定時間ボールを動かさなかった場合にセンサーがスリープ状態になります。スリープ状態の解除に少し時間がかかるため動き出しが遅くなる場合があります。

### トラックボールの動きがおかしい/動かない

* [センサーの位置調整](#トラックボールセンサーをケースに取り付ける)をご確認ください。
* トラックボールのケーブルがコネクタにしっかりささっているか確認してください。
* センサーの仕様として、最大速度24inch/s、最大加速度10Gという制約があります。19.05mmボールの回転速度に換算すると約10回転/sが最大速度で、これを超える速度で回転させた場合にはカーソルが逆方向に動くことがあります。

### 一部のキーが入力できない

* スイッチの足が折れ曲がっていないか、ソケットやダイオードのはんだ付け・向きに問題がないか確認してください。

### トラックボールの移動速度を変えたい/オートマウスレイヤー/スクロールレイヤーを使用したい

* ZMKのinput processorを使用してください。

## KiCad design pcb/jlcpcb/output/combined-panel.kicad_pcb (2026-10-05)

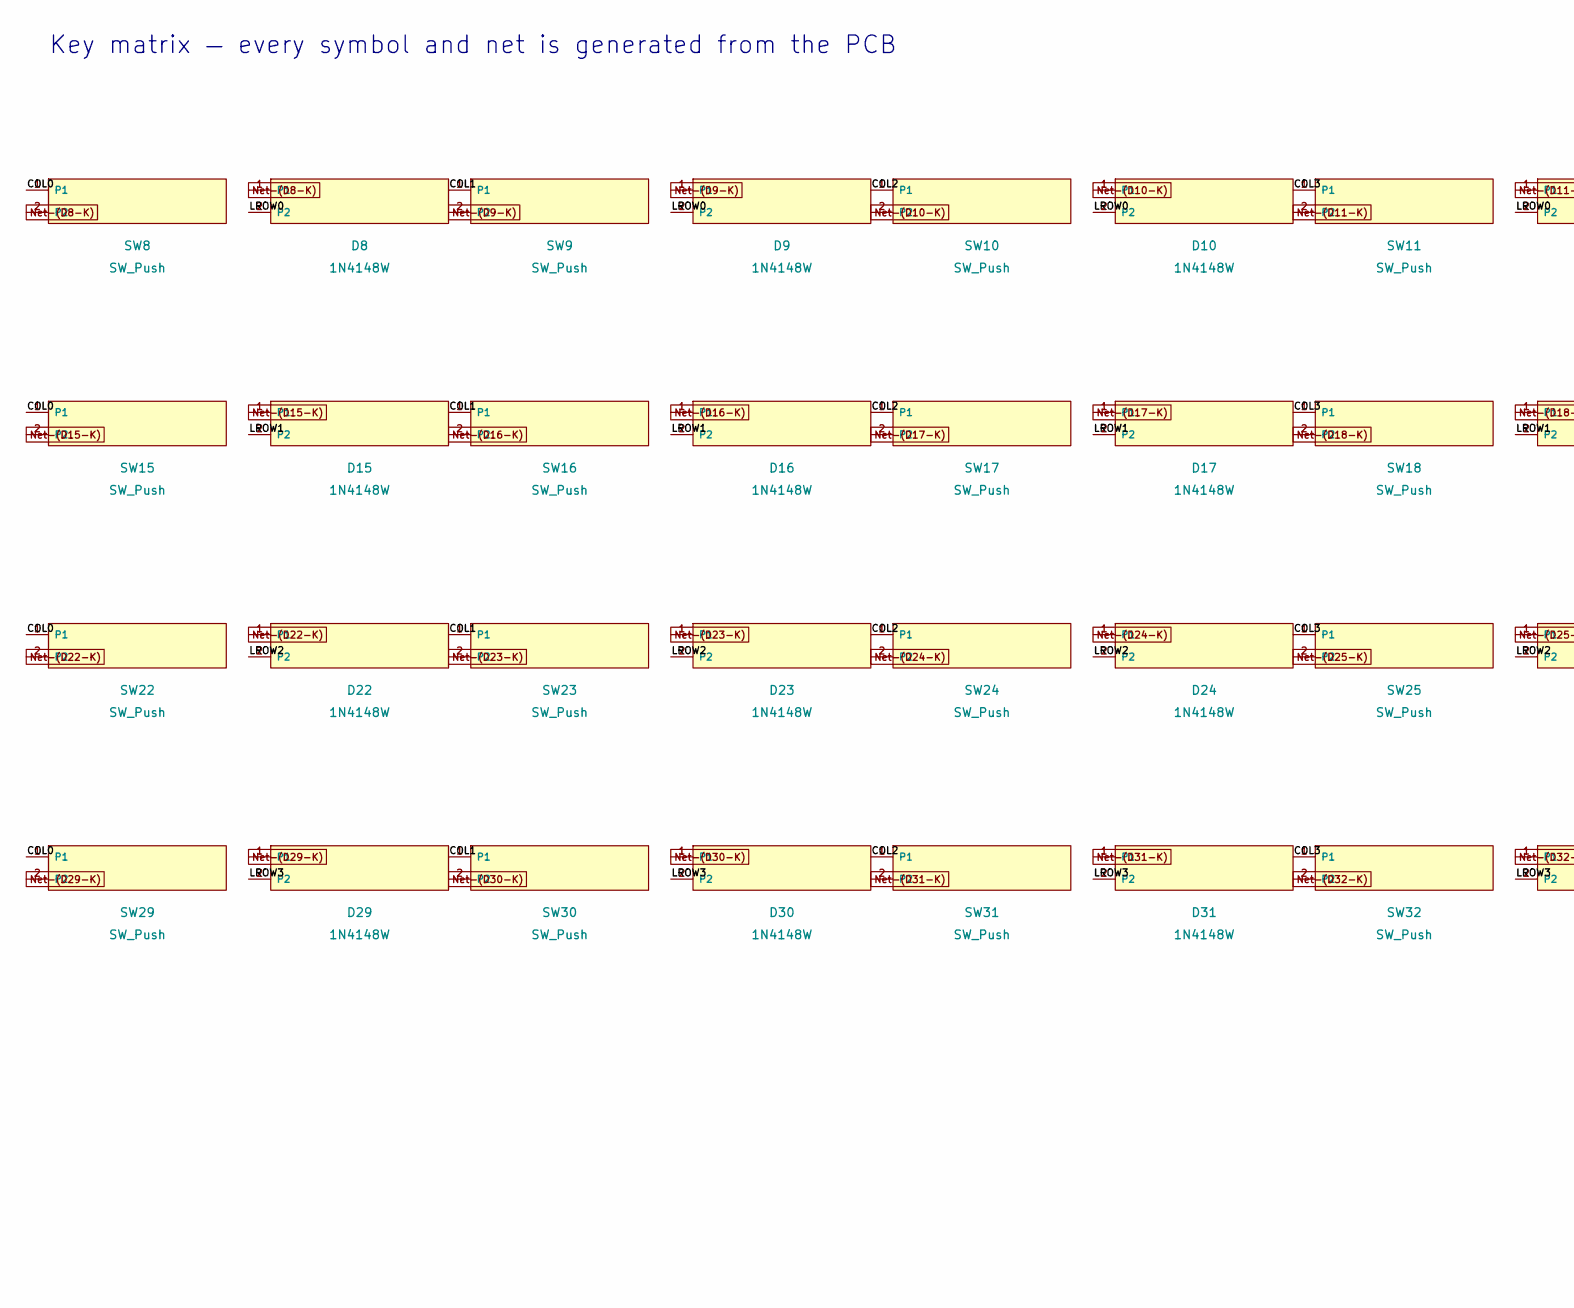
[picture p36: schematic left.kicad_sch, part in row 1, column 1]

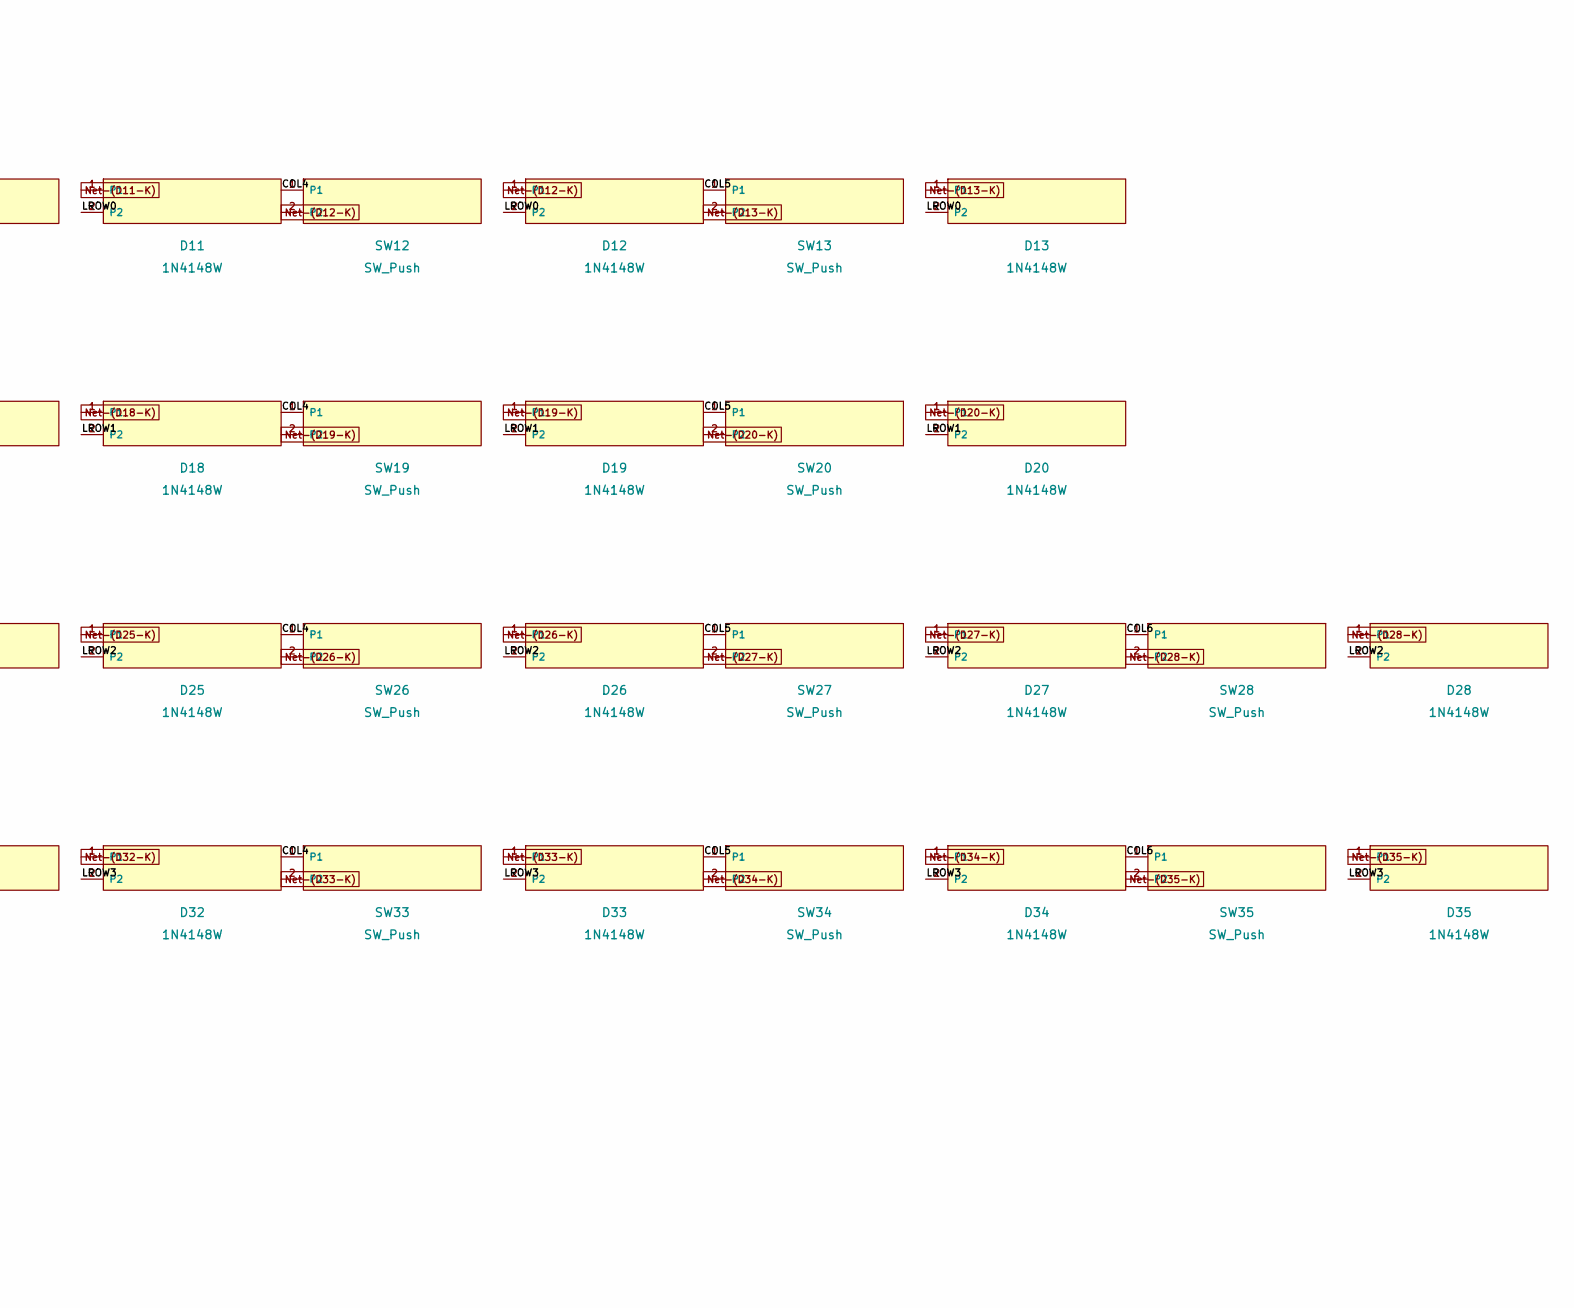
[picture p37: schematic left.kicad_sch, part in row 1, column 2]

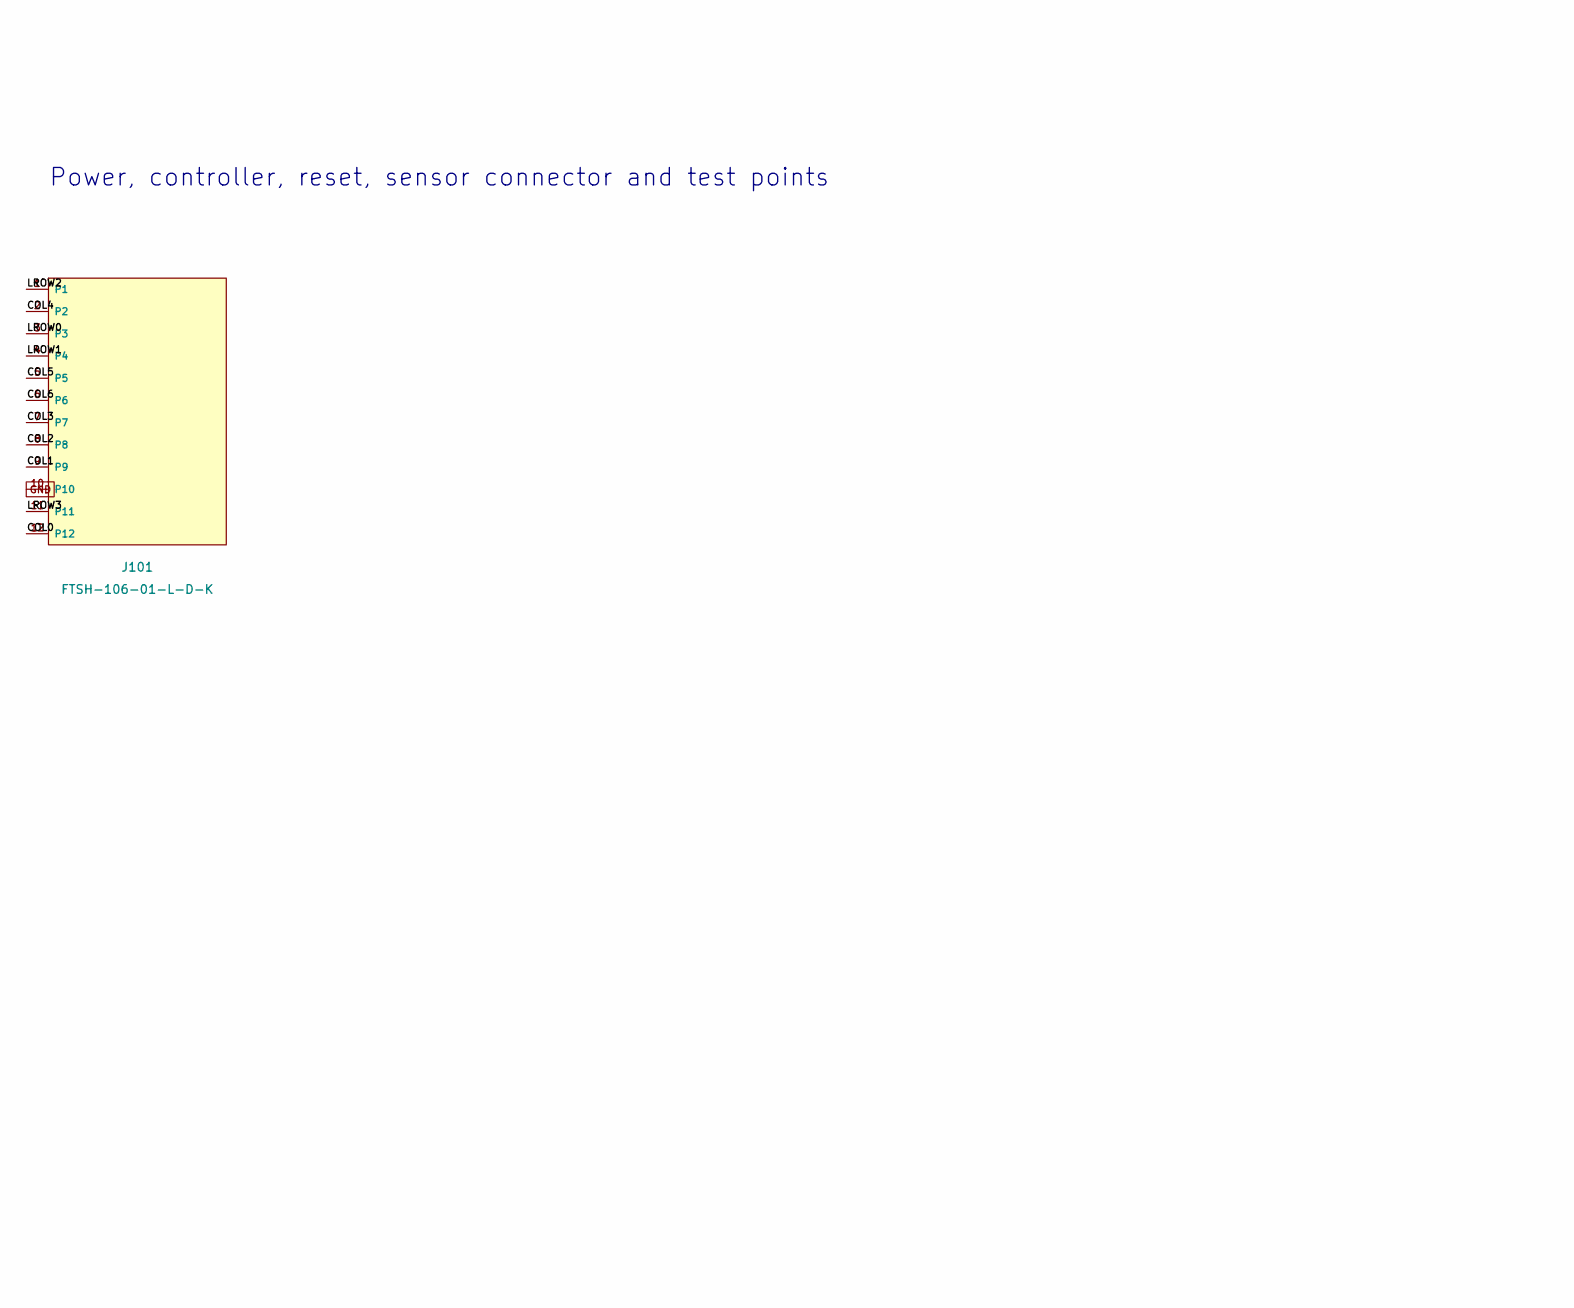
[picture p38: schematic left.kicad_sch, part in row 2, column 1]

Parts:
D8, D9, D10, D11, D12, D13, D15, D16, D17, D18, D19, D20, D22, D23, D24, D25, D26, D27, D28, D29, D30, D31, D32, D33, D34, D35: 1N4148W; D_SOD-123_HandSoldering; MPN 1N4148W; LCSC C81598
J101: FTSH-106-01-L-D-K; Samtec_FTSH-106-01-L-D-K
SW8, SW9, SW10, SW11, SW12, SW13, SW15, SW16, SW17, SW18, SW19, SW20, SW22, SW23, SW24, SW25, SW26, SW27, SW28, SW29, SW30, SW31, SW32, SW33, SW34, SW35: SW_Push; CHOC_V2_SOCKET_HANDSOLDERING_17mm; LCSC C9900009224

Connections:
Board_0-/left/COL0: J101.12, SW8.1, SW15.1, SW22.1, SW29.1
Board_0-/left/COL1: J101.9, SW9.1, SW16.1, SW23.1, SW30.1
Board_0-/left/COL2: J101.8, SW10.1, SW17.1, SW24.1, SW31.1
Board_0-/left/COL3: J101.7, SW11.1, SW18.1, SW25.1, SW32.1
Board_0-/left/COL4: J101.2, SW12.1, SW19.1, SW26.1, SW33.1
Board_0-/left/COL5: J101.5, SW13.1, SW20.1, SW27.1, SW34.1
Board_0-/left/COL6: J101.6, SW28.1, SW35.1
Board_0-/left/LROW0: D8.2 (A), D9.2 (A), D10.2 (A), D11.2 (A), D12.2 (A), D13.2 (A), J101.3
Board_0-/left/LROW1: D15.2 (A), D16.2 (A), D17.2 (A), D18.2 (A), D19.2 (A), D20.2 (A), J101.4
Board_0-/left/LROW2: D22.2 (A), D23.2 (A), D24.2 (A), D25.2 (A), D26.2 (A), D27.2 (A), D28.2 (A), J101.1
Board_0-/left/LROW3: D29.2 (A), D30.2 (A), D31.2 (A), D32.2 (A), D33.2 (A), D34.2 (A), D35.2 (A), J101.11
Board_0-GND: J101.10
Board_0-Net-(D8-K): D8.1 (K), SW8.2
Board_0-Net-(D9-K): D9.1 (K), SW9.2
Board_0-Net-(D10-K): D10.1 (K), SW10.2
Board_0-Net-(D11-K): D11.1 (K), SW11.2
Board_0-Net-(D12-K): D12.1 (K), SW12.2
Board_0-Net-(D13-K): D13.1 (K), SW13.2
Board_0-Net-(D15-K): D15.1 (K), SW15.2
Board_0-Net-(D16-K): D16.1 (K), SW16.2
Board_0-Net-(D17-K): D17.1 (K), SW17.2
Board_0-Net-(D18-K): D18.1 (K), SW18.2
Board_0-Net-(D19-K): D19.1 (K), SW19.2
Board_0-Net-(D20-K): D20.1 (K), SW20.2
Board_0-Net-(D22-K): D22.1 (K), SW22.2
Board_0-Net-(D23-K): D23.1 (K), SW23.2
Board_0-Net-(D24-K): D24.1 (K), SW24.2
Board_0-Net-(D25-K): D25.1 (K), SW25.2
Board_0-Net-(D26-K): D26.1 (K), SW26.2
Board_0-Net-(D27-K): D27.1 (K), SW27.2
Board_0-Net-(D28-K): D28.1 (K), SW28.2
Board_0-Net-(D29-K): D29.1 (K), SW29.2
Board_0-Net-(D30-K): D30.1 (K), SW30.2
Board_0-Net-(D31-K): D31.1 (K), SW31.2
Board_0-Net-(D32-K): D32.1 (K), SW32.2
Board_0-Net-(D33-K): D33.1 (K), SW33.2
Board_0-Net-(D34-K): D34.1 (K), SW34.2
Board_0-Net-(D35-K): D35.1 (K), SW35.2

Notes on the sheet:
Key matrix — every symbol and net is generated from the PCB
Power, controller, reset, sensor connector and test points
Source of truth: PCB pad/net assignment

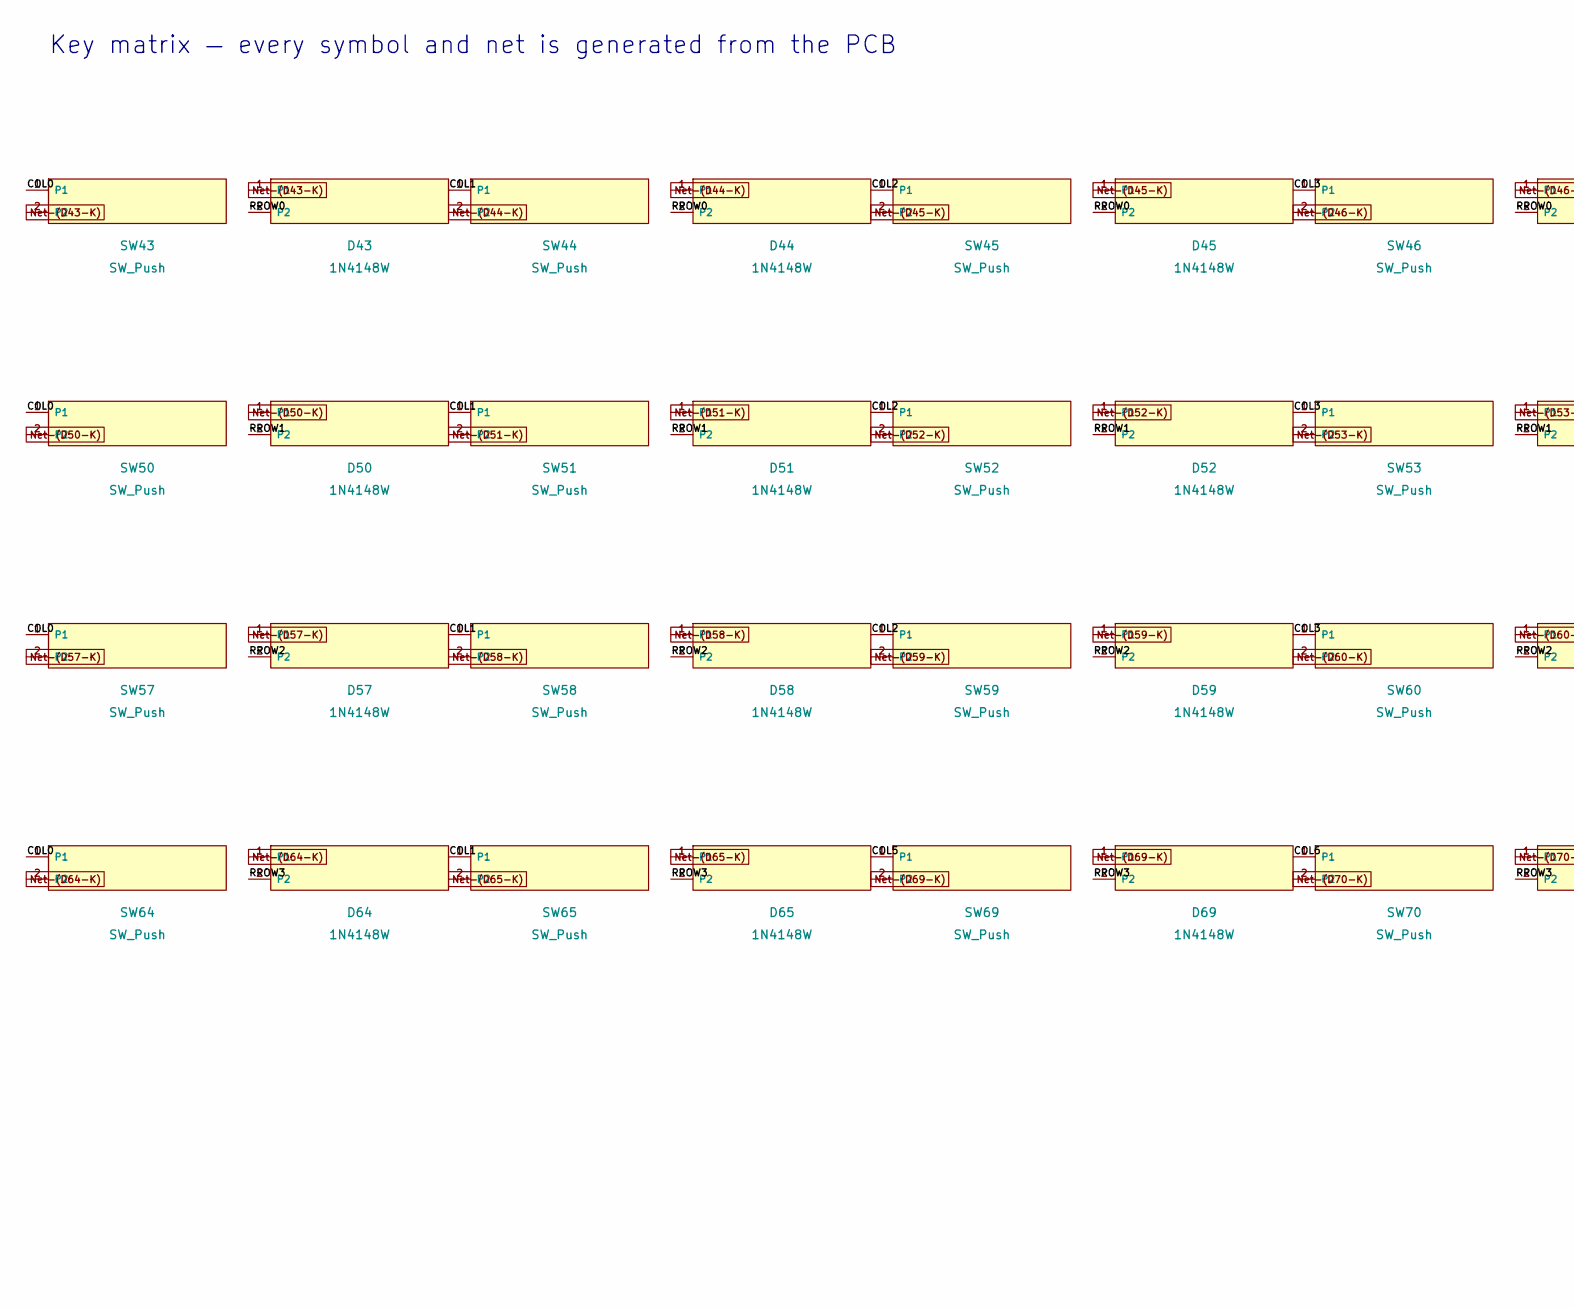
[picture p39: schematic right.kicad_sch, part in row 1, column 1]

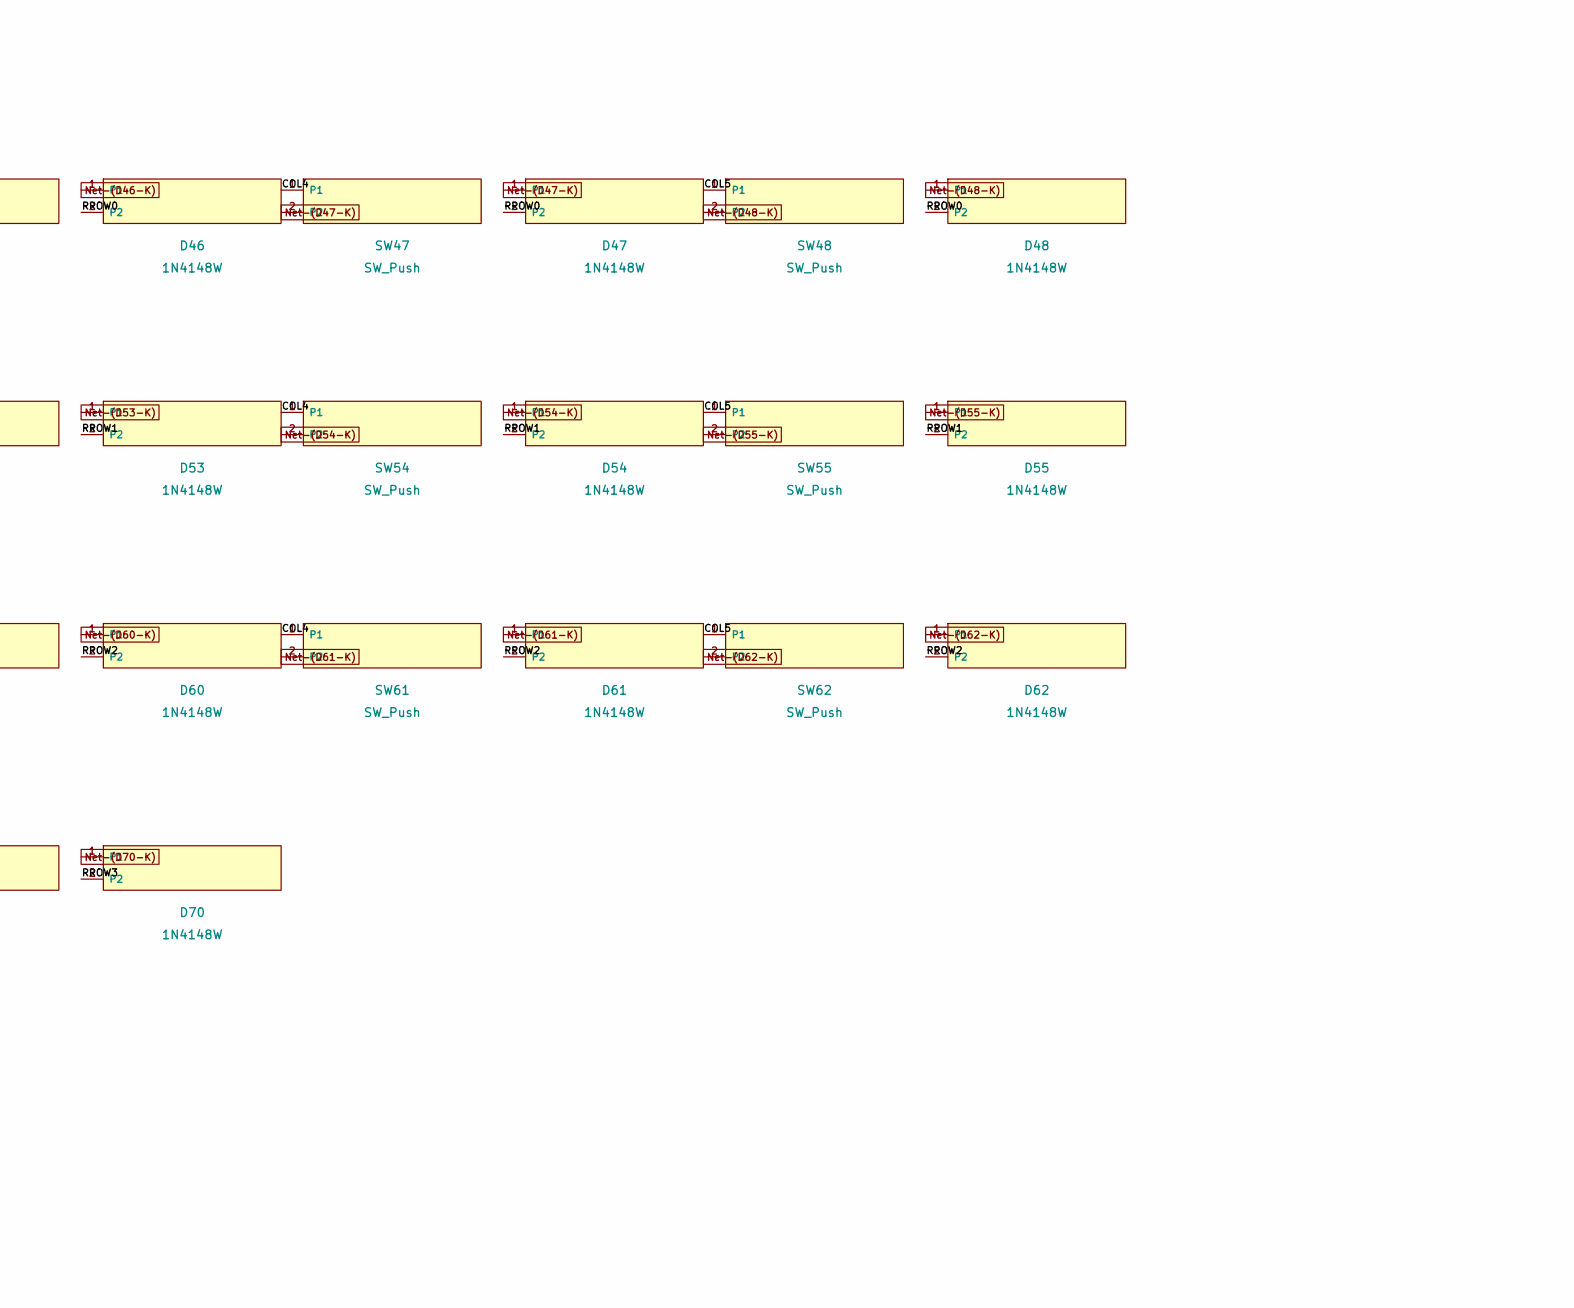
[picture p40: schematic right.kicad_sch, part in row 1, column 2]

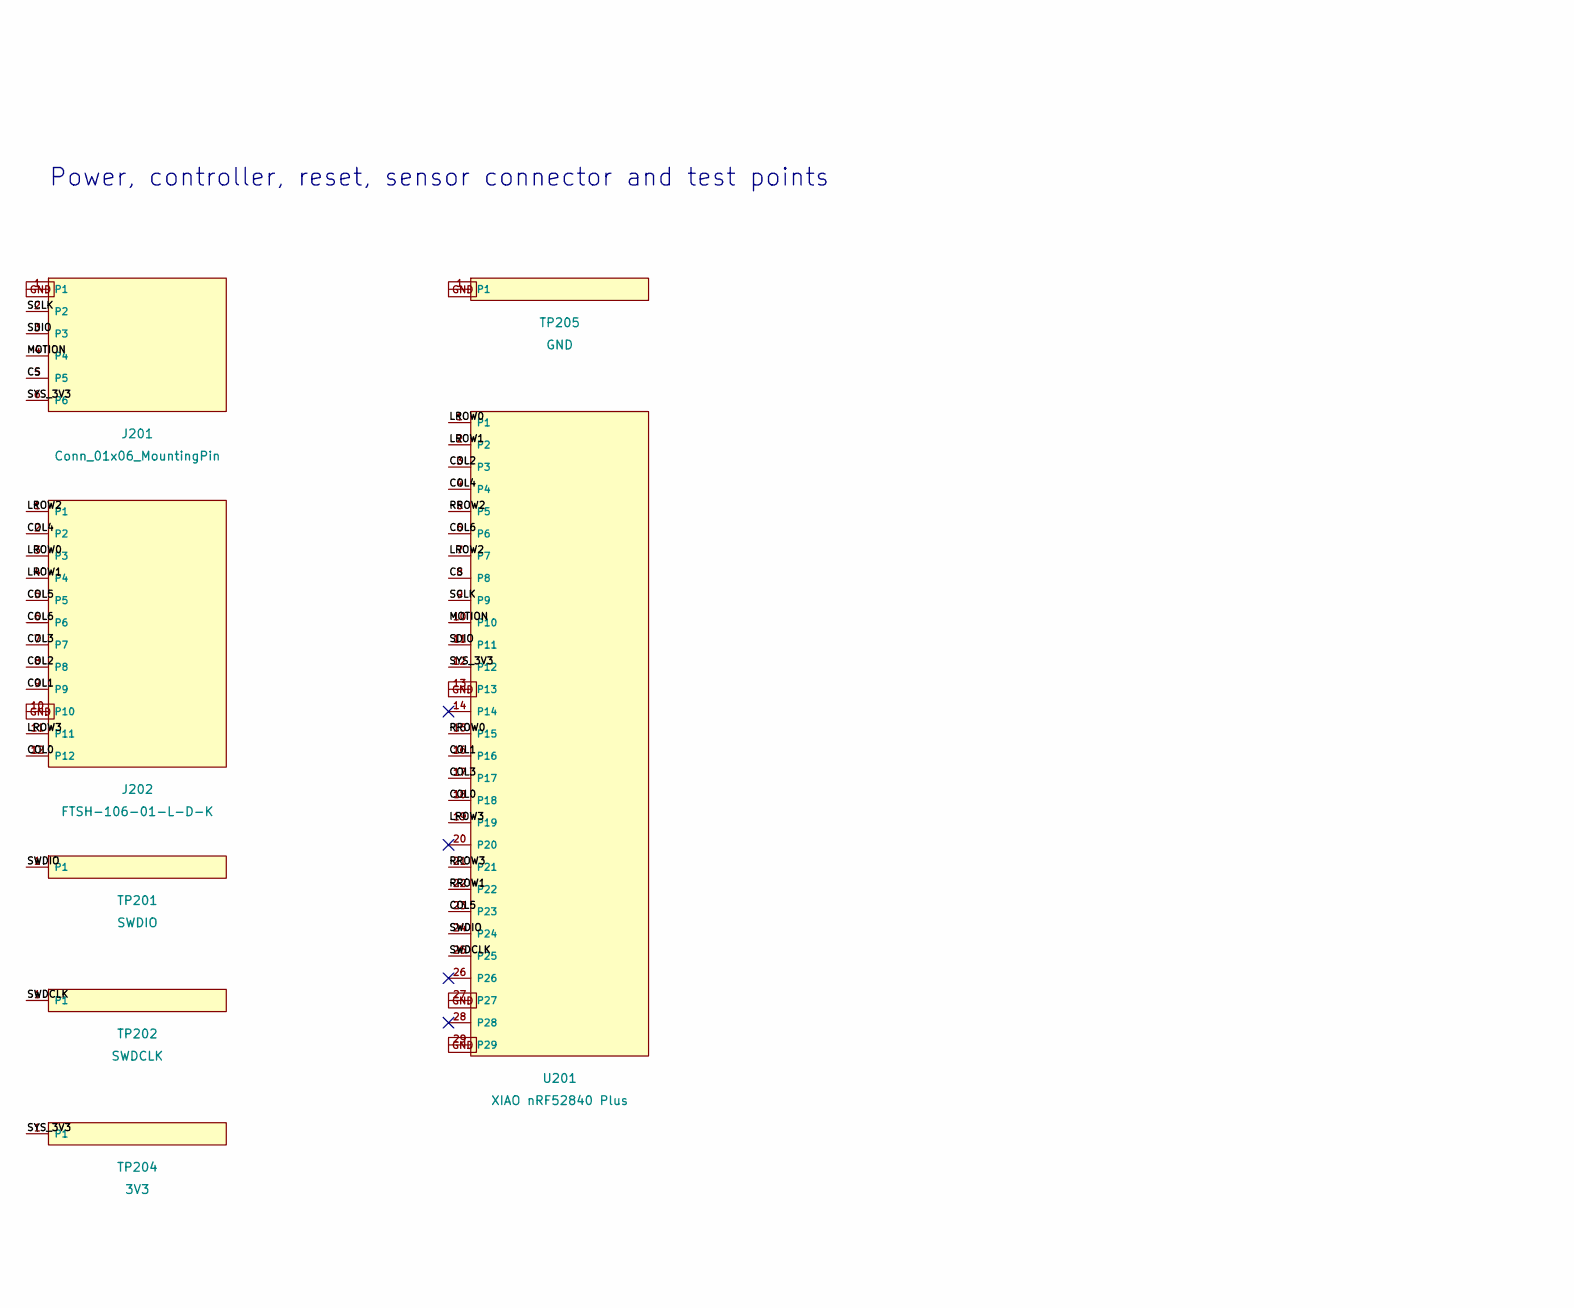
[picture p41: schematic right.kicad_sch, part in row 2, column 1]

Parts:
D43, D44, D45, D46, D47, D48, D50, D51, D52, D53, D54, D55, D57, D58, D59, D60, D61, D62, D64, D65, D69, D70: 1N4148W; D_SOD-123_HandSoldering; MPN 1N4148W; LCSC C81598
J201: Conn_01x06_MountingPin; ffc-6p-adapter
J202: FTSH-106-01-L-D-K; Samtec_FTSH-106-01-L-D-K
SW43, SW44, SW45, SW46, SW47, SW48, SW50, SW51, SW52, SW53, SW54, SW55, SW57, SW58, SW59, SW60, SW61, SW62, SW64, SW65, SW69, SW70: SW_Push; CHOC_V2_SOCKET_HANDSOLDERING_17mm; LCSC C9900009224
TP201: SWDIO; TestPoint_Pad_D1.5mm
TP202: SWDCLK; TestPoint_Pad_D1.5mm
TP204: 3V3; TestPoint_Pad_D1.5mm
TP205: GND; TestPoint_Pad_D1.5mm
U201: XIAO nRF52840 Plus; XIAO-nRF52840-Plus-SMD

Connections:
Board_1-/right/COL0: J202.12, SW43.1, SW50.1, SW57.1, SW64.1, U201.18
Board_1-/right/COL1: J202.9, SW44.1, SW51.1, SW58.1, SW65.1, U201.16
Board_1-/right/COL2: J202.8, SW45.1, SW52.1, SW59.1, U201.3
Board_1-/right/COL3: J202.7, SW46.1, SW53.1, SW60.1, U201.17
Board_1-/right/COL4: J202.2, SW47.1, SW54.1, SW61.1, U201.4
Board_1-/right/COL5: J202.5, SW48.1, SW55.1, SW62.1, SW69.1, U201.23
Board_1-/right/COL6: J202.6, SW70.1, U201.6
Board_1-/right/CS: J201.5, U201.8
Board_1-/right/LROW0: J202.3, U201.1
Board_1-/right/LROW1: J202.4, U201.2
Board_1-/right/LROW2: J202.1, U201.7
Board_1-/right/LROW3: J202.11, U201.19
Board_1-/right/MOTION: J201.4, U201.10
Board_1-/right/RROW0: D43.2 (A), D44.2 (A), D45.2 (A), D46.2 (A), D47.2 (A), D48.2 (A), U201.15
Board_1-/right/RROW1: D50.2 (A), D51.2 (A), D52.2 (A), D53.2 (A), D54.2 (A), D55.2 (A), U201.22
Board_1-/right/RROW2: D57.2 (A), D58.2 (A), D59.2 (A), D60.2 (A), D61.2 (A), D62.2 (A), U201.5
Board_1-/right/RROW3: D64.2 (A), D65.2 (A), D69.2 (A), D70.2 (A), U201.21
Board_1-/right/SCLK: J201.2, U201.9
Board_1-/right/SDIO: J201.3, U201.11
Board_1-/right/SWDCLK: TP202.1, U201.25
Board_1-/right/SWDIO: TP201.1, U201.24
Board_1-/right/SYS_3V3: J201.6, TP204.1, U201.12
Board_1-GND: J201.1, J202.10, TP205.1, U201.13, U201.27, U201.29
Board_1-Net-(D43-K): D43.1 (K), SW43.2
Board_1-Net-(D44-K): D44.1 (K), SW44.2
Board_1-Net-(D45-K): D45.1 (K), SW45.2
Board_1-Net-(D46-K): D46.1 (K), SW46.2
Board_1-Net-(D47-K): D47.1 (K), SW47.2
Board_1-Net-(D48-K): D48.1 (K), SW48.2
Board_1-Net-(D50-K): D50.1 (K), SW50.2
Board_1-Net-(D51-K): D51.1 (K), SW51.2
Board_1-Net-(D52-K): D52.1 (K), SW52.2
Board_1-Net-(D53-K): D53.1 (K), SW53.2
Board_1-Net-(D54-K): D54.1 (K), SW54.2
Board_1-Net-(D55-K): D55.1 (K), SW55.2
Board_1-Net-(D57-K): D57.1 (K), SW57.2
Board_1-Net-(D58-K): D58.1 (K), SW58.2
Board_1-Net-(D59-K): D59.1 (K), SW59.2
Board_1-Net-(D60-K): D60.1 (K), SW60.2
Board_1-Net-(D61-K): D61.1 (K), SW61.2
Board_1-Net-(D62-K): D62.1 (K), SW62.2
Board_1-Net-(D64-K): D64.1 (K), SW64.2
Board_1-Net-(D65-K): D65.1 (K), SW65.2
Board_1-Net-(D69-K): D69.1 (K), SW69.2
Board_1-Net-(D70-K): D70.1 (K), SW70.2

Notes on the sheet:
Key matrix — every symbol and net is generated from the PCB
Power, controller, reset, sensor connector and test points
Source of truth: PCB pad/net assignment

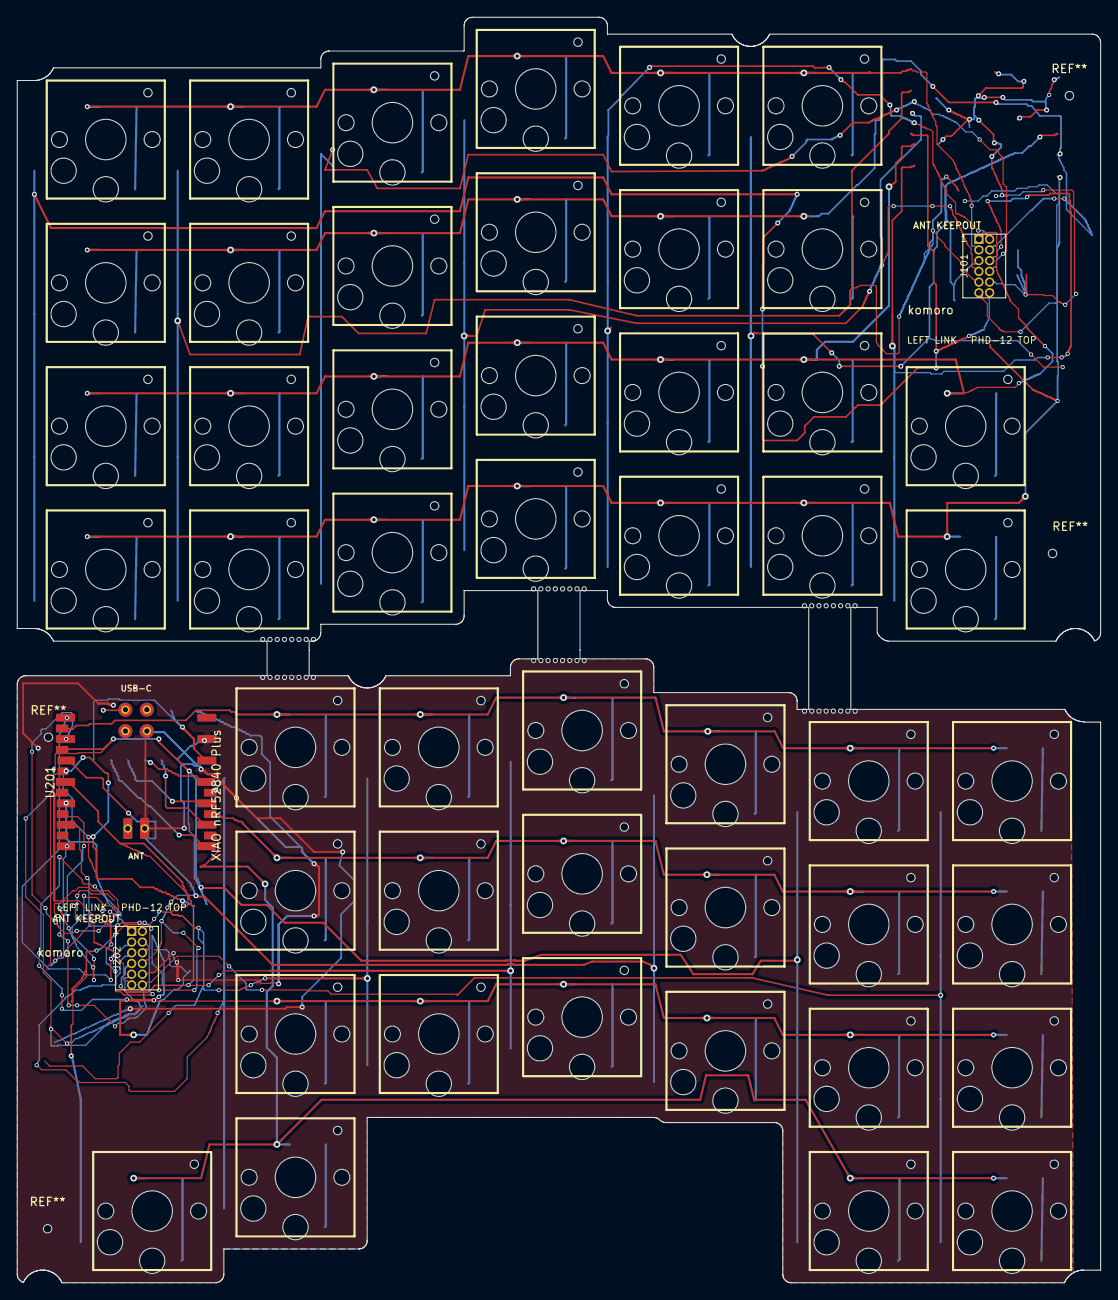
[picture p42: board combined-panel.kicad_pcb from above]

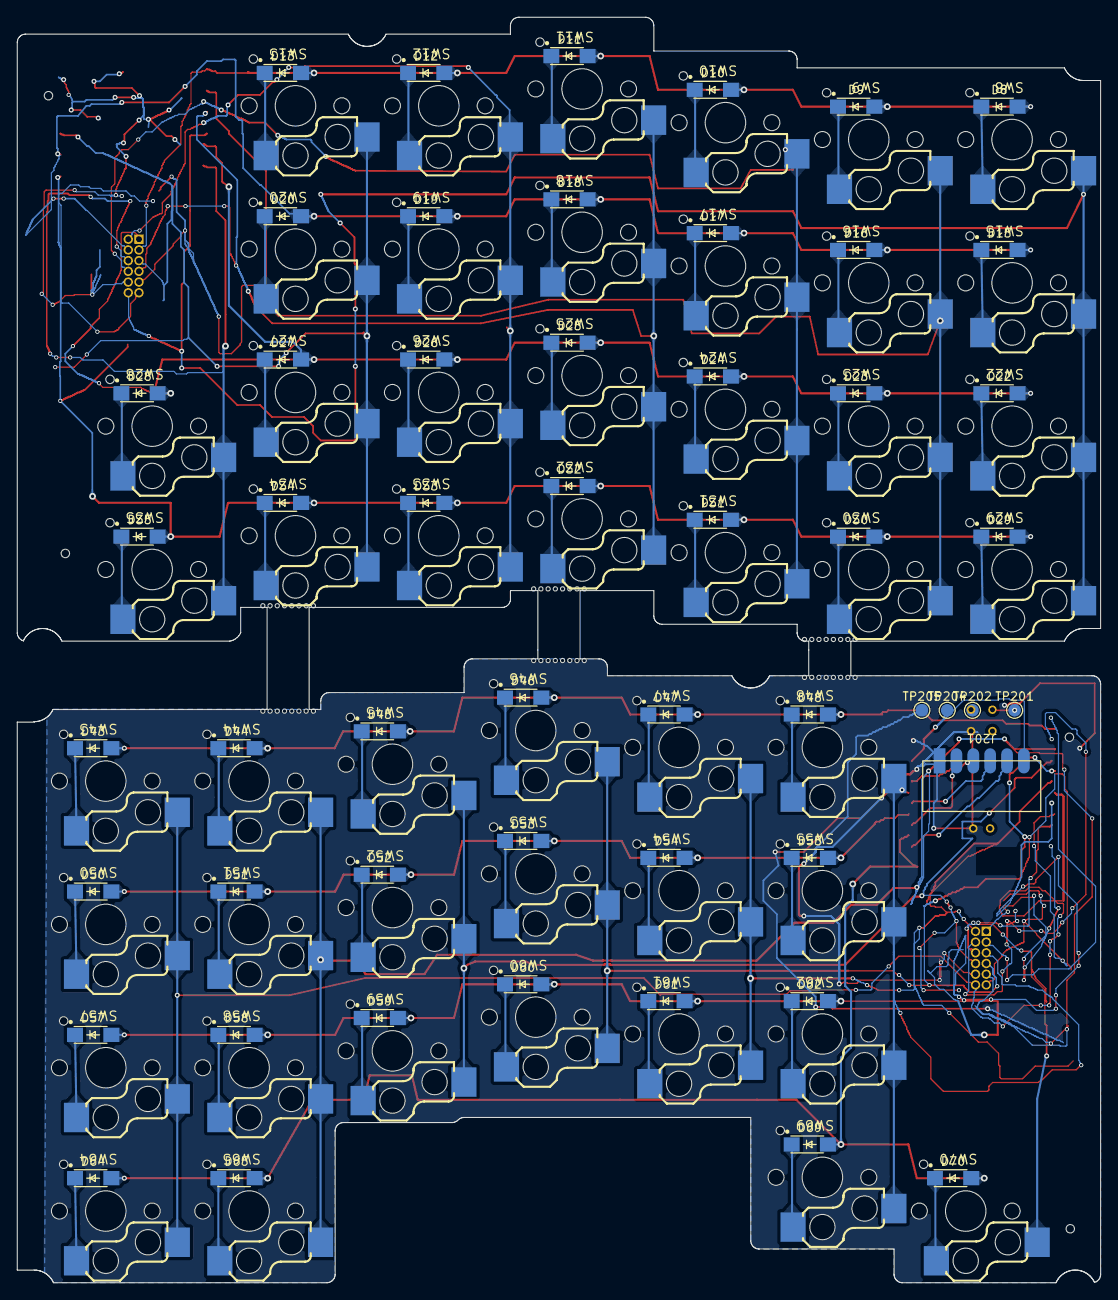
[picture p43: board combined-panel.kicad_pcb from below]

Board: 2 copper layers, 128.5 x 150.1 mm, 152 parts (101 on the bottom side), 82 nets.

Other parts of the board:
KiKit_MB_1_1, KiKit_MB_1_2, KiKit_MB_1_3, KiKit_MB_1_4, KiKit_MB_1_5, KiKit_MB_1_6, KiKit_MB_1_7, KiKit_MB_1_8, KiKit_MB_2_1, KiKit_MB_2_2, KiKit_MB_2_3, KiKit_MB_2_4, KiKit_MB_2_5, KiKit_MB_2_6, KiKit_MB_2_7, KiKit_MB_2_8, KiKit_MB_3_1, KiKit_MB_3_2, KiKit_MB_3_3, KiKit_MB_3_4, KiKit_MB_3_5, KiKit_MB_3_6, KiKit_MB_3_7, KiKit_MB_3_8, KiKit_MB_4_1, KiKit_MB_4_2, KiKit_MB_4_3, KiKit_MB_4_4, KiKit_MB_4_5, KiKit_MB_4_6, KiKit_MB_4_7, KiKit_MB_4_8, KiKit_MB_5_1, KiKit_MB_5_2, KiKit_MB_5_3, KiKit_MB_5_4, KiKit_MB_5_5, KiKit_MB_5_6, KiKit_MB_5_7, KiKit_MB_5_8, KiKit_MB_6_1, KiKit_MB_6_2, KiKit_MB_6_3, KiKit_MB_6_4, KiKit_MB_6_5, KiKit_MB_6_6, KiKit_MB_6_7, KiKit_MB_6_8: NPTH

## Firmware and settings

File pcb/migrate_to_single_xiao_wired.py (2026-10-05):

#!/usr/bin/env python3
"""Convert both komoro halves to one USB-powered XIAO and a passive cable link.

The right PCB retains the XIAO and pointing-device connector.  The left PCB
becomes a passive switch/diode matrix.  A 12-circuit Samtec SHF right-angle
header on the back of each PCB carries four left rows, seven shared columns,
and ground.  The headers mate with a keyed FFTP twisted-pair cable assembly.

Run with KiCad's bundled Python/pcbnew module:

    migrate_to_single_xiao_wired.py LEFT_IN RIGHT_IN LEFT_OUT RIGHT_OUT
"""

from __future__ import annotations

from dataclasses import dataclass
from heapq import heappop, heappush
from pathlib import Path
import math
import sys

import pcbnew


ROOT = Path(__file__).resolve().parent
SHF_LIBRARY = ROOT / "Library.pretty"
SHF_FOOTPRINT = "Samtec_SHF-106-01-L-D-RA"

TRACE_WIDTH = 0.15
VIA_DIAMETER = 0.40
VIA_DRILL = 0.20
CLEARANCE = 0.14
ROUTER_CLEARANCE = 0.14
EDGE_MARGIN = 0.25
GRID = 0.15

F = 0
B = 1
LAYER_ID = (pcbnew.F_Cu, pcbnew.B_Cu)


def mm(value: float) -> int:
    return pcbnew.FromMM(value)


def point(x: float, y: float) -> pcbnew.VECTOR2I:
    return pcbnew.VECTOR2I(mm(x), mm(y))


def get_or_create_net(board: pcbnew.BOARD, name: str) -> pcbnew.NETINFO_ITEM:
    net = board.FindNet(name)
    if net is None:
        net = pcbnew.NETINFO_ITEM(board, name)
        board.Add(net)
    return net


def set_pad_net(
    board: pcbnew.BOARD, footprint: pcbnew.FOOTPRINT, number: str, name: str | None
) -> None:
    pad = footprint.FindPadByNumber(number)
    if pad is None:
        raise RuntimeError(f"{footprint.GetReference()}: pad {number} not found")
    if name is None:
        pad.SetNetCode(0)
    else:
        pad.SetNet(get_or_create_net(board, name))


def rename_net(board: pcbnew.BOARD, old: str, new: str) -> None:
    net = board.FindNet(old)
    if net is None:
        raise RuntimeError(f"net not found: {old}")
    if board.FindNet(new) is not None:
        raise RuntimeError(f"target net already exists: {new}")
    net.SetNetname(new)


def remove_net_copper(board: pcbnew.BOARD, names: set[str]) -> None:
    for item in list(board.GetTracks()):
        if item.GetNetname() in names:
            board.RemoveNative(item)


def remove_footprints(board: pcbnew.BOARD, references: set[str]) -> None:
    for reference in references:
        footprint = board.FindFootprintByReference(reference)
        if footprint is not None:
            board.RemoveNative(footprint)


def load_shf(
    board: pcbnew.BOARD,
    reference: str,
    x: float,
    y: float,
    angle: float,
) -> pcbnew.FOOTPRINT:
    # Build the footprint in memory instead of depending on KiCad's GUI-backed
    # plugin loader.  The checked-in .kicad_mod is the editable library source;
    # these dimensions mirror it so this migration also works headlessly.
    footprint = pcbnew.FOOTPRINT(board)
    footprint.SetFPID(pcbnew.LIB_ID("Library", SHF_FOOTPRINT))
    footprint.SetReference(reference)
    footprint.SetValue("SHF-106-01-L-D-RA")
    footprint.SetLayer(pcbnew.B_Cu)
    footprint.Reference().SetLayer(pcbnew.B_SilkS)
    footprint.Reference().SetVisible(False)
    footprint.Value().SetLayer(pcbnew.B_Fab)
    footprint.Value().SetVisible(False)
    for index in range(12):
        pad = pcbnew.PAD(footprint)
        pad.SetNumber(str(index + 1))
        pad.SetAttribute(pcbnew.PAD_ATTRIB_PTH)
        pad.SetShape(pcbnew.PAD_SHAPE_RECT if index == 0 else pcbnew.PAD_SHAPE_CIRCLE)
        pad.SetSize(pcbnew.VECTOR2I(mm(1.0), mm(1.0)))
        pad.SetDrillSize(pcbnew.VECTOR2I(mm(0.65), mm(0.65)))
        pad.SetLayerSet(pad.PTHMask())
        pad.SetPosition(point(1.27 if index % 2 else 0.0, 1.27 * (index // 2)))
        footprint.Add(pad)

    def fp_line(
        start: tuple[float, float],
        end: tuple[float, float],
        layer: int,
        width: float,
    ) -> None:
        line = pcbnew.PCB_SHAPE(footprint)
        line.SetShape(pcbnew.SHAPE_T_SEGMENT)
        line.SetStart(point(*start))
        line.SetEnd(point(*end))
        line.SetLayer(layer)
        line.SetWidth(mm(width))
        footprint.Add(line)

    body = [(-0.95, -2.92), (9.91, -2.92), (9.91, 9.27), (-0.95, 9.27)]
    for start, end in zip(body, body[1:] + body[:1]):
        fp_line(start, end, pcbnew.B_Fab, 0.1)
    silk = [(-0.95, -1.2), (0.1, -2.92), (9.91, -2.92), (9.91, 9.27), (-0.95, 9.27), (-0.95, -1.2)]
    for start, end in zip(silk, silk[1:]):
        fp_line(start, end, pcbnew.B_SilkS, 0.12)
    courtyard = [(-1.25, -3.22), (10.21, -3.22), (10.21, 9.57), (-1.25, 9.57)]
    for start, end in zip(courtyard, courtyard[1:] + courtyard[:1]):
        fp_line(start, end, pcbnew.B_CrtYd, 0.05)

    footprint.SetPosition(point(x, y))
    footprint.SetOrientationDegrees(angle)
    footprint.SetAttributes(
        footprint.GetAttributes()
        | pcbnew.FP_EXCLUDE_FROM_BOM
        | pcbnew.FP_EXCLUDE_FROM_POS_FILES
    )
    board.Add(footprint)
    return footprint


def add_label(
    board: pcbnew.BOARD,
    value: str,
    x: float,
    y: float,
    angle: float = 0,
    layer: int = pcbnew.F_SilkS,
) -> None:
    label = pcbnew.PCB_TEXT(board)
    label.SetText(value)
    label.SetPosition(point(x, y))
    label.SetTextAngle(pcbnew.EDA_ANGLE(angle, pcbnew.DEGREES_T))
    label.SetLayer(layer)
    label.SetTextSize(pcbnew.VECTOR2I(mm(0.8), mm(0.8)))
    label.SetTextThickness(mm(0.12))
    board.Add(label)


def clean_obsolete_labels(board: pcbnew.BOARD) -> None:
    obsolete = {
        "XCL103D503CR-G",
        "XC8111AA01MR-G",
        "BOOST",
        "BATTERY",
        "BMP Boost",
    }
    for drawing in list(board.GetDrawings()):
        if isinstance(drawing, pcbnew.PCB_TEXT):
            text = drawing.GetText()
            if text in obsolete or "BATT" in text or "BOOST" in text:
                board.RemoveNative(drawing)


def pad_endpoint(footprint: pcbnew.FOOTPRINT, number: str) -> "Endpoint":
    pad = footprint.FindPadByNumber(number)
    if pad is None:
        raise RuntimeError(f"{footprint.GetReference()}: pad {number} missing")
    position = pad.GetPosition()
    if pad.IsOnLayer(pcbnew.F_Cu) and pad.IsOnLayer(pcbnew.B_Cu):
        layer = None
    elif pad.IsOnLayer(pcbnew.F_Cu):
        layer = F
    elif pad.IsOnLayer(pcbnew.B_Cu):
        layer = B
    else:
        raise RuntimeError(f"{footprint.GetReference()}:{number} has no copper layer")
    return Endpoint(pcbnew.ToMM(position.x), pcbnew.ToMM(position.y), layer)


@dataclass(frozen=True)
class Endpoint:
    x: float
    y: float
    layer: int | None


def item_net(item) -> str:
    try:
        return item.GetNetname()
    except Exception:
        return ""


def box_mm(item) -> tuple[float, float, float, float]:
    box = item.GetBoundingBox()
    return (
        pcbnew.ToMM(box.GetLeft()),
        pcbnew.ToMM(box.GetTop()),
        pcbnew.ToMM(box.GetRight()),
        pcbnew.ToMM(box.GetBottom()),
    )


class LocalRouter:
    def __init__(
        self,
        board: pcbnew.BOARD,
        net_name: str,
        start: Endpoint,
        goal: Endpoint,
        margin: float = 16.0,
    ) -> None:
        self.board = board
        self.net_name = net_name
        self.start = start
        self.goal = goal
        self.x_min = min(start.x, goal.x) - margin
        self.x_max = max(start.x, goal.x) + margin
        self.y_min = min(start.y, goal.y) - margin
        self.y_max = max(start.y, goal.y) + margin
        self.nx = round((self.x_max - self.x_min) / GRID) + 1
        self.ny = round((self.y_max - self.y_min) / GRID) + 1

    def cell(self, x: float, y: float) -> tuple[int, int]:
        return (
            round((x - self.x_min) / GRID),
            round((y - self.y_min) / GRID),
        )

    def xy(self, ix: int, iy: int) -> tuple[float, float]:
        return self.x_min + ix * GRID, self.y_min + iy * GRID

    def mark_box(
        self,
        blocked: list[set[tuple[int, int]]],
        layers,
        bounds,
        inflate: float,
    ) -> None:
        left, top, right, bottom = bounds
        ix0, iy0 = self.cell(left - inflate, top - inflate)
        ix1, iy1 = self.cell(right + inflate, bottom + inflate)
        for layer in layers:
            target = blocked[layer]
            for ix in range(max(0, ix0), min(self.nx - 1, ix1) + 1):
                for iy in range(max(0, iy0), min(self.ny - 1, iy1) + 1):
                    target.add((ix, iy))

    def obstacles(
        self,
    ) -> tuple[list[set[tuple[int, int]]], list[set[tuple[int, int]]]]:
        blocked = [set(), set()]
        via_blocked = [set(), set()]
        outline = pcbnew.SHAPE_POLY_SET()
        self.board.GetBoardPolygonOutlines(outline, True)
        for ix in range(self.nx):
            for iy in range(self.ny):
                x, y = self.xy(ix, iy)
                probes = (
                    (x, y),
                    (x - EDGE_MARGIN, y),
                    (x + EDGE_MARGIN, y),
                    (x, y - EDGE_MARGIN),
                    (x, y + EDGE_MARGIN),
                )
                if any(not outline.Contains(point(px, py)) for px, py in probes):
                    blocked[F].add((ix, iy))
                    blocked[B].add((ix, iy))
                    via_blocked[F].add((ix, iy))
                    via_blocked[B].add((ix, iy))

        trace_inflate = ROUTER_CLEARANCE + TRACE_WIDTH / 2
        via_inflate = ROUTER_CLEARANCE + VIA_DIAMETER / 2
        for footprint in self.board.GetFootprints():
            for pad in footprint.Pads():
                if item_net(pad) == self.net_name:
                    continue
                layers = []
                if pad.IsOnLayer(pcbnew.F_Cu):
                    layers.append(F)
                if pad.IsOnLayer(pcbnew.B_Cu):
                    layers.append(B)
                if layers:
                    bounds = box_mm(pad)
                    self.mark_box(blocked, layers, bounds, trace_inflate)
                    self.mark_box(via_blocked, layers, bounds, via_inflate)

        for track in self.board.GetTracks():
            if item_net(track) == self.net_name:
                continue
            if isinstance(track, pcbnew.PCB_VIA):
                bounds = box_mm(track)
                self.mark_box(blocked, (F, B), bounds, trace_inflate)
                self.mark_box(via_blocked, (F, B), bounds, via_inflate)
            else:
                layer = F if track.GetLayer() == pcbnew.F_Cu else B
                bounds = box_mm(track)
                self.mark_box(blocked, (layer,), bounds, trace_inflate)
                self.mark_box(via_blocked, (layer,), bounds, via_inflate)

        # Filled copper zones are regenerated after routing.  Treating their
        # current bounding boxes as solid obstacles would make every ground
        # plane impassable; pad/track clearance and the final DRC are the
        # authoritative checks here.
        return blocked, via_blocked

    def solve(self):
        blocked, via_blocked = self.obstacles()
        sx, sy = self.cell(self.start.x, self.start.y)
        gx, gy = self.cell(self.goal.x, self.goal.y)
        start_layers = (F, B) if self.start.layer is None else (self.start.layer,)
        goal_layers = (F, B) if self.goal.layer is None else (self.goal.layer,)
        starts = [(sx, sy, layer) for layer in start_layers]
        goals = {(gx, gy, layer) for layer in goal_layers}
        for ix, iy, layer in starts:
            blocked[layer].discard((ix, iy))
            via_blocked[layer].discard((ix, iy))
        for ix, iy, layer in goals:
            blocked[layer].discard((ix, iy))
            via_blocked[layer].discard((ix, iy))

        def heuristic(node):
            ix, iy, layer = node
            return min(
                math.hypot(ix - gx, iy - gy) + (0 if layer == gl else 10)
                for _, _, gl in goals
            )

        moves = (
            (1, 0, 1.0),
            (-1, 0, 1.0),
            (0, 1, 1.0),
            (0, -1, 1.0),
            (1, 1, math.sqrt(2)),
            (1, -1, math.sqrt(2)),
            (-1, 1, math.sqrt(2)),
            (-1, -1, math.sqrt(2)),
        )
        queue = []
        distance = {}
        previous = {}
        serial = 0
        for node in starts:
            distance[node] = 0.0
            heappush(queue, (heuristic(node), 0.0, serial, node))
            serial += 1

        reached = None
        while queue:
            _, cost, _, current = heappop(queue)
            if cost != distance.get(current):
                continue
            if current in goals:
                reached = current
                break
            ix, iy, layer = current
            for dx, dy, move_cost in moves:
                nx, ny = ix + dx, iy + dy
                if not (0 <= nx < self.nx and 0 <= ny < self.ny):
                    continue
                if (nx, ny) in blocked[layer]:
                    continue
                nxt = (nx, ny, layer)
                new_cost = cost + move_cost
                if new_cost < distance.get(nxt, float("inf")):
                    distance[nxt] = new_cost
                    previous[nxt] = current
                    heappush(queue, (new_cost + heuristic(nxt), new_cost, serial, nxt))
                    serial += 1
            other = 1 - layer
            if (
                (ix, iy) not in blocked[other]
                and (ix, iy) not in via_blocked[F]
                and (ix, iy) not in via_blocked[B]
            ):
                nxt = (ix, iy, other)
                new_cost = cost + 12.0
                if new_cost < distance.get(nxt, float("inf")):
                    distance[nxt] = new_cost
                    previous[nxt] = current
                    heappush(queue, (new_cost + heuristic(nxt), new_cost, serial, nxt))
                    serial += 1

        if reached is None:
            raise RuntimeError(
                f"no route for {self.net_name}: {self.start} -> {self.goal}"
            )
        path = [reached]
        while path[-1] not in starts:
            path.append(previous[path[-1]])
        path.reverse()
        return path

    def add(self, path) -> None:
        net = self.board.FindNet(self.net_name)
        raw = [(self.start.x, self.start.y, path[0][2])]
        raw.extend((*self.xy(ix, iy), layer) for ix, iy, layer in path)
        raw.append((self.goal.x, self.goal.y, path[-1][2]))

        compact = [raw[0]]
        for item in raw[1:]:
            if item == compact[-1]:
                continue
            if len(compact) >= 2 and item[2] == compact[-1][2] == compact[-2][2]:
                ax, ay, _ = compact[-2]
                bx, by, _ = compact[-1]
                cx, cy, _ = item
                if abs((bx - ax) * (cy - by) - (by - ay) * (cx - bx)) < 1e-6:
                    compact[-1] = item
                    continue
            compact.append(item)

        for a, b in zip(compact, compact[1:]):
            if a[2] != b[2]:
                via = pcbnew.PCB_VIA(self.board)
                via.SetPosition(point(a[0], a[1]))
                via.SetWidth(mm(VIA_DIAMETER))
                via.SetDrill(mm(VIA_DRILL))
                via.SetLayerPair(pcbnew.F_Cu, pcbnew.B_Cu)
                via.SetNet(net)
                self.board.Add(via)
            elif abs(a[0] - b[0]) > 1e-6 or abs(a[1] - b[1]) > 1e-6:
                track = pcbnew.PCB_TRACK(self.board)
                track.SetStart(point(a[0], a[1]))
                track.SetEnd(point(b[0], b[1]))
                track.SetWidth(mm(TRACE_WIDTH))
                track.SetLayer(LAYER_ID[a[2]])
                track.SetNet(net)
                self.board.Add(track)


def route_pads(
    board: pcbnew.BOARD,
    net_name: str,
    start_fp: pcbnew.FOOTPRINT,
    start_pad: str,
    goal_fp: pcbnew.FOOTPRINT,
    goal_pad: str,
    margin: float = 16.0,
) -> None:
    router = LocalRouter(
        board,
        net_name,
        pad_endpoint(start_fp, start_pad),
        pad_endpoint(goal_fp, goal_pad),
        margin,
    )
    path = router.solve()
    router.add(path)
    print(
        f"routed {net_name}: {start_fp.GetReference()}:{start_pad} -> "
        f"{goal_fp.GetReference()}:{goal_pad} ({len(path)} nodes)"
    )


def nearest_copper_endpoint(
    board: pcbnew.BOARD, net_name: str, origin: Endpoint, min_distance: float = 0.0
) -> Endpoint:
    """Return the closest point on existing routed copper for a net."""
    best: tuple[float, Endpoint] | None = None
    for item in board.GetTracks():
        if item_net(item) != net_name:
            continue
        if isinstance(item, pcbnew.PCB_VIA):
            pos = item.GetPosition()
            candidate = Endpoint(pcbnew.ToMM(pos.x), pcbnew.ToMM(pos.y), None)
        else:
            start = item.GetStart()
            end = item.GetEnd()
            ax, ay = pcbnew.ToMM(start.x), pcbnew.ToMM(start.y)
            bx, by = pcbnew.ToMM(end.x), pcbnew.ToMM(end.y)
            dx, dy = bx - ax, by - ay
            length2 = dx * dx + dy * dy
            if length2 == 0:
                ratio = 0.0
            else:
                ratio = max(
                    0.0,
                    min(1.0, ((origin.x - ax) * dx + (origin.y - ay) * dy) / length2),
                )
            candidate = Endpoint(
                ax + ratio * dx,
                ay + ratio * dy,
                F if item.GetLayer() == pcbnew.F_Cu else B,
            )
        distance = math.hypot(candidate.x - origin.x, candidate.y - origin.y)
        if distance < min_distance:
            continue
        if best is None or distance < best[0]:
            best = (distance, candidate)
    if best is None:
        raise RuntimeError(f"no routed copper found for {net_name}")
    return best[1]


def route_pad_to_endpoint(
    board: pcbnew.BOARD,
    net_name: str,
    start_fp: pcbnew.FOOTPRINT,
    start_pad: str,
    goal: Endpoint,
    margin: float = 16.0,
) -> None:
    start = pad_endpoint(start_fp, start_pad)
    if start_fp.GetValue() == "SHF-106-01-L-D-RA":
        pad_x = [pcbnew.ToMM(pad.GetPosition().x) for pad in start_fp.Pads()]
        center_x = (min(pad_x) + max(pad_x)) / 2
        escape_layer = B if start.x < center_x else F
        escape = Endpoint(
            start.x + (-1.2 if start.x < center_x else 1.2),
            start.y,
            escape_layer,
        )
        track = pcbnew.PCB_TRACK(board)
        track.SetStart(point(start.x, start.y))
        track.SetEnd(point(escape.x, escape.y))
        track.SetWidth(mm(TRACE_WIDTH))
        track.SetLayer(LAYER_ID[escape_layer])
        track.SetNet(board.FindNet(net_name))
        board.Add(track)
        start = escape
    router = LocalRouter(board, net_name, start, goal, margin)
    try:
        path = router.solve()
        router.add(path)
    except RuntimeError:
        distance = math.hypot(start.x - goal.x, start.y - goal.y)
        if distance > 3.0 or goal.layer is None:
            raise
        track = pcbnew.PCB_TRACK(board)
        track.SetStart(point(start.x, start.y))
        track.SetEnd(point(goal.x, goal.y))
        track.SetWidth(mm(TRACE_WIDTH))
        track.SetLayer(LAYER_ID[goal.layer])
        track.SetNet(board.FindNet(net_name))
        board.Add(track)
        path = [(0, 0, goal.layer)]
    print(
        f"routed {net_name}: {start_fp.GetReference()}:{start_pad} -> "
        f"copper@({goal.x:.2f},{goal.y:.2f}) ({len(path)} nodes)"
    )


LINK_PIN_NETS = {
    "1": "GND",
    "2": "COL0",
    "3": "COL1",
    "4": "COL2",
    "5": "COL3",
    "6": "COL4",
    "7": "COL5",
    "8": "COL6",
    "9": "LROW0",
    "10": "LROW1",
    "11": "LROW2",
    "12": "LROW3",
}

XIAO_MATRIX_PADS = {
    "LROW0": "1",
    "LROW1": "2",
    "LROW2": "7",
    "LROW3": "19",
    "RROW0": "15",
    "RROW1": "22",
    "RROW2": "5",
    "RROW3": "21",
    "COL0": "18",
    "COL1": "16",
    "COL2": "3",
    "COL3": "17",
    "COL4": "4",
    "COL5": "23",
    "COL6": "6",
}

OLD_MATRIX_PADS = {
    "ROW1": "15",
    "ROW2": "22",
    "ROW3": "5",
    "ROW4": "21",
    "COL0": "18",
    "COL1": "16",
    "COL2": "3",
    "COL3": "17",
    "COL4": "4",
    "COL5": "23",
    "COL6": "6",
}


def assign_link_nets(
    board: pcbnew.BOARD, connector: pcbnew.FOOTPRINT, side: str
) -> dict[str, str]:
    names = {}
    for pin, short_name in LINK_PIN_NETS.items():
        name = "GND" if short_name == "GND" else f"/{side}/{short_name}"
        set_pad_net(board, connector, pin, name)
        names[short_name] = name
    return names
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

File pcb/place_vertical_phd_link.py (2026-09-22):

#!/usr/bin/env python3
"""Replace the split link headers with top-entry JST PHD connectors.

The right connector is centered directly below the XIAO.  The left connector
uses the equivalent location below the former left-XIAO position.  Both are
through-hole B12B-PHDSS headers for hand soldering and mate with PHDR-12VS
cable housings inserted from the top of the keyboard.

This is a one-time migration helper, not a repeatable manufacturing step.
The left-side routing search may run out of space depending on route order;
the checked PCB files are the authoritative output.  The right-side path
has been reproduced and DRC-checked separately.

Run with KiCad's bundled Python/pcbnew module:

    place_vertical_phd_link.py LEFT_IN RIGHT_IN LEFT_OUT RIGHT_OUT
"""

from __future__ import annotations

from collections import defaultdict
from pathlib import Path
import os
import math
import sys

import pcbnew
import migrate_to_single_xiao_wired as routerlib

from migrate_to_single_xiao_wired import (
    Endpoint,
    LINK_PIN_NETS,
    LocalRouter,
    TRACE_WIDTH,
    VIA_DIAMETER,
    VIA_DRILL,
    add_label,
    finish,
    get_or_create_net,
    mm,
    nearest_copper_endpoint,
    pad_endpoint,
    point,
    remove_link_labels,
    route_pad_to_endpoint,
    set_pad_net,
)


KICAD_FOOTPRINT_LIBRARY = Path(
    "/Applications/KiCad/KiCad.app/Contents/SharedSupport/footprints/Connector_JST.pretty"
)
FOOTPRINT_NAME = "JST_PHD_B12B-PHDSS_2x06_P2.00mm_Vertical"
NEW_TRACE_WIDTH = 0.15
NEW_VIA_DIAMETER = 0.50
NEW_VIA_DRILL = 0.25


def inside_box(position: pcbnew.VECTOR2I, box: tuple[float, float, float, float]) -> bool:
    x = pcbnew.ToMM(position.x)
    y = pcbnew.ToMM(position.y)
    x0, y0, x1, y1 = box
    return x0 <= x <= x1 and y0 <= y <= y1


def remove_old_link_copper(
    board: pcbnew.BOARD,
    net_names: set[str],
    box: tuple[float, float, float, float],
) -> dict[str, list[Endpoint]]:
    """Remove fanout copper and return every surviving boundary endpoint."""
    boundary: dict[str, list[Endpoint]] = defaultdict(list)
    for item in list(board.GetTracks()):
        if item.GetNetname() not in net_names:
            continue
        if isinstance(item, pcbnew.PCB_VIA):
            remove = inside_box(item.GetPosition(), box)
        else:
            start_inside = inside_box(item.GetStart(), box)
            end_inside = inside_box(item.GetEnd(), box)
            remove = start_inside or end_inside
            layer = 0 if item.GetLayer() == pcbnew.F_Cu else 1
            if start_inside and not end_inside:
                end = item.GetEnd()
                boundary[item.GetNetname()].append(
                    Endpoint(pcbnew.ToMM(end.x), pcbnew.ToMM(end.y), layer)
                )
            elif end_inside and not start_inside:
                start = item.GetStart()
                boundary[item.GetNetname()].append(
                    Endpoint(pcbnew.ToMM(start.x), pcbnew.ToMM(start.y), layer)
                )
        if remove:
            board.RemoveNative(item)
    return boundary


def load_vertical_phd(
    board: pcbnew.BOARD,
    reference: str,
    position: tuple[float, float],
    angle: float,
) -> pcbnew.FOOTPRINT:
    footprint = pcbnew.FootprintLoad(str(KICAD_FOOTPRINT_LIBRARY), FOOTPRINT_NAME)
    if footprint is None:
        raise RuntimeError(f"unable to load {FOOTPRINT_NAME}")
    footprint.SetReference(reference)
    footprint.SetValue("B12B-PHDSS")
    footprint.SetFPID(pcbnew.LIB_ID("Connector_JST", FOOTPRINT_NAME))
    footprint.SetLayer(pcbnew.F_Cu)
    footprint.SetPosition(point(*position))
    footprint.SetOrientationDegrees(angle)
    footprint.SetAttributes(
        footprint.GetAttributes()
        | pcbnew.FP_EXCLUDE_FROM_BOM
        | pcbnew.FP_EXCLUDE_FROM_POS_FILES
    )
    board.Add(footprint)
    return footprint


def one_goal_per_component(
    board: pcbnew.BOARD, net_name: str, goals: list[Endpoint]
) -> list[Endpoint]:
    """Discard stale cut points and keep one point per copper component."""
    board.BuildConnectivity()
    connectivity = board.GetConnectivity()
    selected: dict[frozenset[str], Endpoint] = {}
    tracks = [item for item in board.GetTracks() if item.GetNetname() == net_name]
    for goal in goals:
        candidate = None
        for item in tracks:
            positions = (
                (item.GetPosition(),)
                if isinstance(item, pcbnew.PCB_VIA)
                else (item.GetStart(), item.GetEnd())
            )
            if any(
                math.hypot(
                    pcbnew.ToMM(position.x) - goal.x,
                    pcbnew.ToMM(position.y) - goal.y,
                )
                < 0.01
                for position in positions
            ):
                candidate = item
                break
        if candidate is None:
            continue
        connected = list(connectivity.GetConnectedItems(candidate)) + [candidate]
        signature = frozenset(item.m_Uuid.AsString() for item in connected)
        selected.setdefault(signature, goal)
    return list(selected.values())


def add_pad_escape(
    board: pcbnew.BOARD,
    net_name: str,
    connector: pcbnew.FOOTPRINT,
    pin: str,
) -> Endpoint:
    """Add a perpendicular dog-bone escape and return its via endpoint."""
    start = pad_endpoint(connector, pin)
    pad_y = [pad_endpoint(connector, pad.GetNumber()).y for pad in connector.Pads()]
    center_y = (min(pad_y) + max(pad_y)) / 2
    escape = Endpoint(start.x, start.y + (-2.5 if start.y < center_y else 2.5), None)

    # The 2.00 mm pitch leaves no legal channel between adjacent 1.70 mm
    # plated pads.  A perpendicular dog-bone escape keeps every trace clear.
    track = pcbnew.PCB_TRACK(board)
    track.SetStart(point(start.x, start.y))
    track.SetEnd(point(escape.x, escape.y))
    track.SetWidth(mm(NEW_TRACE_WIDTH))
    track.SetLayer(pcbnew.F_Cu)
    track.SetNet(board.FindNet(net_name))
    board.Add(track)

    via = pcbnew.PCB_VIA(board)
    via.SetPosition(point(escape.x, escape.y))
    via.SetWidth(mm(NEW_VIA_DIAMETER))
    via.SetDrill(mm(NEW_VIA_DRILL))
    via.SetLayerPair(pcbnew.F_Cu, pcbnew.B_Cu)
    via.SetNet(board.FindNet(net_name))
    board.Add(via)
    return escape


def route_link_escape(
    board: pcbnew.BOARD, net_name: str, connector: pcbnew.FOOTPRINT, pin: str,
    start: Endpoint, goal,
) -> None:
    """Route a previously reserved pad escape to existing copper."""

    router = LocalRouter(board, net_name, start, goal, 28.0)
    path = router.solve()
    router.add(path)
    print(f"routed {net_name}: {connector.GetReference()}:{pin} -> copper")
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

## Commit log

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2026-08-24 Add outer key columns to split PCBs
    [torabo-tsuki-lp-S-ortho-mini-left.kicad_pcb, torabo-tsuki-lp-S-ortho-mini-right.kicad_pcb]
2026-08-25 Adapt split keyboard PCBs for AAA battery holders
    [left.kicad_sch, right.kicad_sch, torabo-tsuki-lp-S-ortho-mini-left.kicad_pcb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]
2026-08-27 Migrate split PCBs to XIAO nRF52840 Plus
    [torabo-tsuki-lp-S-ortho-mini-left.kicad_pcb, torabo-tsuki-lp-S-ortho-mini-right.kicad_pcb]
2026-08-28 Compact XIAO and battery PCB layout
    [torabo-tsuki-lp-S-ortho-mini-left.kicad_pcb, torabo-tsuki-lp-S-ortho-mini-right.kicad_pcb]
2026-08-30 Convert split PCBs to column stagger
    [torabo-tsuki-lp-S-ortho-mini-left.kicad_pcb, torabo-tsuki-lp-S-ortho-mini-right.kicad_pcb]
2026-08-30 Refine staggered PCB outlines and mounting clearances
    [torabo-tsuki-lp-S-ortho-mini-left.kicad_pcb, torabo-tsuki-lp-S-ortho-mini-right.kicad_pcb]
2026-08-30 Round exposed PCB outline corners
    [torabo-tsuki-lp-S-ortho-mini-left.kicad_pcb, torabo-tsuki-lp-S-ortho-mini-right.kicad_pcb]
2026-08-30 Fix staggered keyboard routing
    [torabo-tsuki-lp-S-ortho-mini-left.kicad_pcb, torabo-tsuki-lp-S-ortho-mini-right.kicad_pcb]
2026-08-30 Prepare split keyboard PCBs for JLCPCB assembly
    [left-bom.csv, left.kicad_sch, right-bom.csv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]
2026-09-04 Address JLCDFM manufacturing warnings
    [torabo-tsuki-lp-S-ortho-mini-left.kicad_pcb, torabo-tsuki-lp-S-ortho-mini-right.kicad_pcb]
2026-09-04 Add combined JLCPCB assembly panel
    [combined-bom.csv, combined-panel.kicad_pcb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]
2026-09-04 Rename PCB silkscreen to kb-1
    [combined-panel.kicad_pcb, torabo-tsuki-lp-S-ortho-mini-left.kicad_pcb, torabo-tsuki-lp-S-ortho-mini-right.kicad_pcb]
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2026-09-04 Add right-side boost circuit to PCBA
    [combined-bom.csv, combined-panel.kicad_pcb, right-bom.csv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]
2026-09-05 Add reproducible FreeCAD keyboard case
    [left-bottom-tray.stl, left-top-plate.stl, right-bottom-tray.stl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]
2026-09-05 Recess trackball mounting screw heads
    [right-bottom-tray.stl, torabo-tsuki-om-keyboard-case.FCStd]
2026-09-05 Open battery access and clear XIAO modules
    [left-top-plate.stl, right-top-plate.stl, torabo-tsuki-om-keyboard-case.FCStd]
2026-09-05 Fix XIAO top plate feature orientation
    [left-bottom-tray.stl, left-top-plate.stl, right-bottom-tray.stl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]
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2026-09-14 docs: document XIAO reset jumper wiring
2026-09-20 Fix switch and USB-C case clearances
    [left-bottom-tray.stl, left-top-plate.stl, right-bottom-tray.stl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]
2026-09-20 Refine keyboard case clearances from fit tests
    [left-bottom-tray.stl, left-top-plate.stl, right-bottom-tray.stl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]
2026-09-21 WIP: checkpoint single-XIAO PCB and vertical PHD conversion
    Preserve the current single-controller PCB, schematics, documentation, and manufacturing artifacts. Include the vertical PHD placement/routing experiment; its candidate boards still fail DRC and are not production-ready.
    [combined-bom.csv, combined-panel.kicad_pcb, left-bom.csv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]
2026-09-22 Use vertical JST PHD connectors on split PCBs
    [combined-panel.kicad_pcb, left.kicad_sch, right.kicad_sch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]
2026-09-23 Replace split connectors with Samtec FFSD-compatible headers (#29)
    [combined-panel.kicad_pcb, left.kicad_sch, right.kicad_sch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]
2026-09-23 Shrink inner edges of split PCBs
    [combined-panel.kicad_pcb, torabo-tsuki-lp-S-ortho-mini-left.kicad_pcb, torabo-tsuki-lp-S-ortho-mini-right.kicad_pcb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]
2026-09-23 Remove key below right split connector
    [combined-bom.csv, combined-panel.kicad_pcb, right-bom.csv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]
2026-09-23 Fit right PCB outline around inner key
    [combined-panel.kicad_pcb, torabo-tsuki-lp-S-ortho-mini-right.kicad_pcb]
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2026-09-23 Improve XIAO and trackball adapter solder access
    [combined-panel.kicad_pcb, torabo-tsuki-lp-S-ortho-mini-right.kicad_pcb]
2026-09-24 Add routed screw reliefs to both PCBs and panel
    [combined-panel.kicad_pcb, torabo-tsuki-lp-S-ortho-mini-left.kicad_pcb, torabo-tsuki-lp-S-ortho-mini-right.kicad_pcb]
2026-09-24 Use standard 0.3 mm vias for JLCPCB panels
    [combined-panel.kicad_pcb, torabo-tsuki-lp-S-ortho-mini-left.kicad_pcb, torabo-tsuki-lp-S-ortho-mini-right.kicad_pcb]
2026-09-24 Reduce mouse-bite web for cleaner panel separation
    [combined-panel.kicad_pcb]
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2026-09-26 Add regenerated left bottom tray STL
    [left-bottom-tray.stl]
2026-09-26 Add regenerated case CAD and STL artifacts
    [left-top-plate.stl, right-bottom-tray.stl, right-top-plate.stl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]
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2026-09-27 Fit XIAO USB-C shell in right top case
    [right-top-plate.stl, torabo-tsuki-om-keyboard-case.FCStd]
2026-09-27 Refine XIAO USB hood and label window
    [right-top-plate.stl, torabo-tsuki-om-keyboard-case.FCStd]
2026-09-27 Clear USB-C plug approach at right top plate
    [right-top-plate.stl, torabo-tsuki-om-keyboard-case.FCStd]
2026-09-27 Match switch windows to reference top plate
    [left-top-plate.stl, right-top-plate.stl, torabo-tsuki-om-keyboard-case.FCStd]
2026-09-27 Fit split cable openings and extend trackball floor
    [left-top-plate.stl, right-bottom-tray.stl, right-top-plate.stl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]
2026-09-27 Round trackball floor corner and support screw bosses
    [left-bottom-tray.stl, right-bottom-tray.stl, torabo-tsuki-om-keyboard-case.FCStd]
2026-09-27 Lower keyboard trays and add aligned magnet pockets
    [left-bottom-tray.stl, left-top-plate.stl, right-bottom-tray.stl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]
2026-09-28 Add recessed cable channel to keyboard trays
    [left-bottom-tray.stl, right-bottom-tray.stl, torabo-tsuki-om-keyboard-case.FCStd]
2026-09-29 Fit right trackball tray floor and mounting slot
    [right-bottom-tray.stl, torabo-tsuki-om-keyboard-case.FCStd]
2026-10-03 Fit trackball sensor with a through slot and reinforced back (#49)
    [trackball-case-19mm-ortho-sensor-fit-Body.stl, trackball-case-19mm-ortho-sensor-fit.FCStd, trackball-case-19mm-ortho.FCStd]
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2026-10-04 Remove obsolete top and bottom case PCBs (#51)
    [torabo-tsuki-lp-S-ortho-mini-bottom.kicad_pcb, torabo-tsuki-lp-S-ortho-mini-top.kicad_pcb]
2026-10-04 Rename keyboard to FORT-48 (#52)
    [combined-panel.kicad_pcb, torabo-tsuki-lp-S-ortho-mini-left.kicad_pcb, torabo-tsuki-lp-S-ortho-mini-right.kicad_pcb]
2026-10-04 Add open 19 mm trackball case prototype (#53)
    [trackball-case-19mm-open-Body.stl, trackball-case-19mm-open.FCStd]
2026-10-05 Rename keyboard to komoro (#54)
    [combined-panel.kicad_pcb, torabo-tsuki-lp-S-ortho-mini-left.kicad_pcb, torabo-tsuki-lp-S-ortho-mini-right.kicad_pcb]
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
